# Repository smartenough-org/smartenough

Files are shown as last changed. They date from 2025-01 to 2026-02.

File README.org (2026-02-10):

* SmartEnough
SmartEnough is an open source smart home solution that combines affordable
off-the-shelf hardware with a robust software architecture. Built for people
that don't want to pay premium for each IO they add to the system, who want to
trust the system's reliability and who are not afraid of some tinkering.

** SmartEnough design goals
- Extra cheap hardware: doable by hand (soldering iron or breadboard) and
  upgradable to something more sturdy with ordered PCBs. 48+ IO per single board
  possible and way cheaper $/IO than in any available commercial solutions.
- Robust, resiliant, secure: communication and power over twisted pair cables -
  no batteries, no radio, no cloud.
- Supports house wiring in "constellation of star topologies". We don't have a
  device in each light switch or socket, but neither are we limited to a single
  central control point. Cables from lights/shutters and switches should meet
  somewhere in one or more electrical boxes that are connected together with a
  twisted pair cable to form a CAN bus. Bus can span multiple devices in single
  electrical box, or connect multiple points in a bus or semi-bus configuration.
- Instant response to input.
- Event on one board can cause an action on another (eg. stair switches) via a
  bus without requiring a computer and HomeAssistant - eg. stair lighting.
- Can gather door/window/movement sensor data and be used as an alarm system.
- Open & customizable: I'm building it to suit my needs, trying to keep it open
  for any additional sensible functions.
- Integrates with HomeAssistant, but can do a lot without it.

** Resources
The core system software is in two repositories:
- [[https://github.com/smartenough-org/io-ctrl][io-ctrl]]:
  Firmware for IO controller board that handles IO - reads switches and
  sensors, changes outputs. Contains also firmware for hardware part (left side)
  of =CAN<->USB<->MQTT= bridge to talk to HomeAssistant.
- [[https://github.com/smartenough-org/io-gate][io-gate]]:
  computer part of =CAN<->USB<->MQT= bridge (right part) to convert CAN
  messages to MQTT events that can be understood by HomeAssistant.
- Firmware is in Rust, written with Embassy framework for STM32G431 device.
  Should migrate easy enough to other chips assuming enough peripherals are
  available (CAN and USB working together, 128kB+ Flash, 32kB+ RAM).

Rest of the resources include:
- KiCAD (schematic + board) designs for IO controller board (can be used for
  gate as well).
- KiCAD for organized power injection with protection.
- KiCAD for additional ESPHOME boards for less critical components (like
  temperature sensors).
- 3D printing (FreeCad) designs for DIN rail (mount in electrical boxes) and
  other project boxes for boards (OpenSCAD).
- This repository in addition can contain anything smarthome related I might
  publish (eg. some micropython watering experiments)

** Example deployment
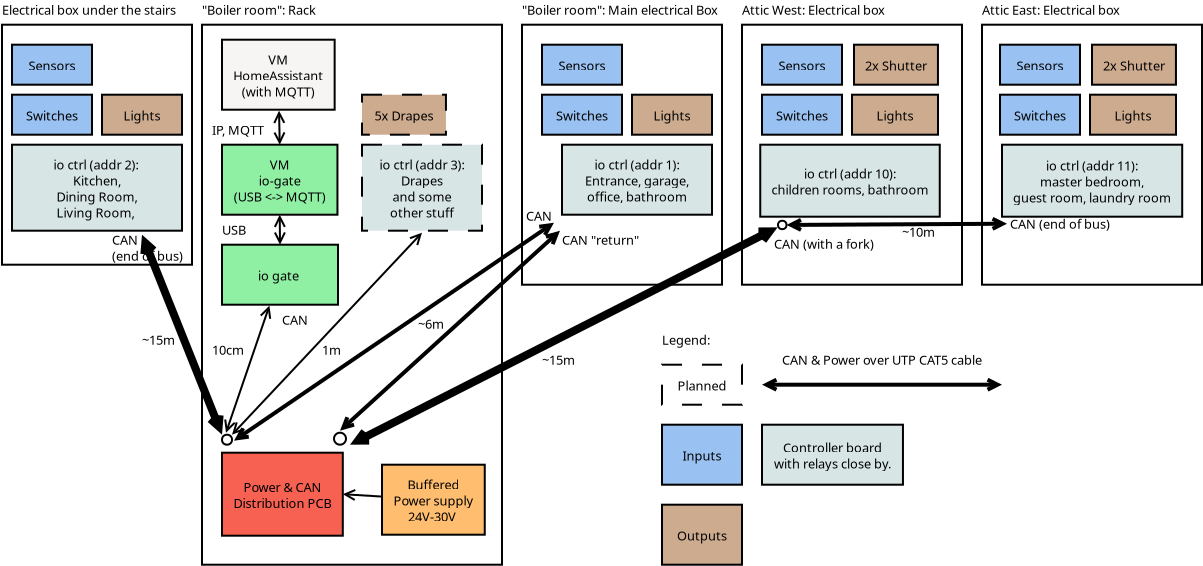
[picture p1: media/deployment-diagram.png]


That's my currently working deployment. NOTE: CAN should not be a star, it
should be a bus. Hence in one case I send CAN signal back over another cable
pair in the same cable to "flatten" it out. Bus gets longer (it's around 50m
total), but stubs are shorter.

*** Connecting cables
I use two pairs for power, one for CAN and one for optional CAN return and a bit
weird RJ45 wiring to indicate the cable is a "SMART" cable not Ethernet. I also
mark those in a visible way. Anything will work as long as CAN and FORWARD is in
the same twisted pair (my mapping will work with normal T568B too).

| T568B | CAN  |   |                       |
|-------+------+---+-----------------------|
| w-o   | w-o  | 1 | CAN_L                 |
| o     | o    | 2 | CAN_H                 |
| w-g   | w-g  | 3 | IN POWER, 24V         |
| bl    | g    | 4 | IN POWER, GND (swap!) |
| w-bl  | w-bl | 5 | IN POWER, 24V         |
| g     | bl   | 6 | IN POWER, GND (swap!) |
| w-br  | w-br | 7 | CAN_L FORWARD         |
| br    | br   | 8 | CAN_H FORWARD         |

*** CAN configuration
I use CAN because it's a multi-master bus, no "leader" device on the BUS needs
to poll for data from "following" devices. When input event occurs or output
changes state a board broadcasts a message on the bus. Another board can see
this message and react by changing it's outputs.

Gate is a special device that serves as a bidirectional =CAN<->USB<->MQTT=
bridge. It receives CAN messages, converts them and publishes them on MQTT. It
also subscribes to MQTT topics and if something is published there it sends a
CAN request to for example toggle an Output.

I use 250kbps CAN speed and 11-bit addressing. I opted for a simple CAN protocol
(as opposed to more versatile CANopen). Address relates to a "message" more than
a "sender/receiver" and is used in determining the priority on the bus. Given
that:
- Messages must be properly unique,
- lower values have higher priorities,
- we want at least 64 devices on the bus,
I picked 6 bit for device address and 5 for message type (32 different message
types). Format: =TTTTTAAAAAA (T)ype + (A)ddress=.

Reporting errors, propagating output/input changes, setting output has higher
priority than requesting status, reporting status, time announcements or some
debug ping/pong messages.

Message body consists of up to 8 bytes of data, system typically uses 2-3.
Example: Request output change has 2 bytes: Index of output to change and byte
representing state (Off, On, Toggle). Message address points at the device that
should change output ("destination").

Message "Output changed" has similarly output index and state (Off, On), but
address points to a message source instead. I don't use RTR (remote frames).

Conscise list of used commands (but see message.rs for details):
- ERROR 0x02 - Error happened.
- OUTPUT_CHANGED 0x04 - My output changed
- INPUT_CHANGED 0x05 -  My input was changed
- SET_OUTPUT 0x08 - Set output X to Y (or invert state)
- CALL_PROC 0x0A - Call a predefined procedure in VM
- CALL_SHUTTER 0x0B - Pass command to Shutter code
- STATUS_IO 0x0E - My current IO status, not necessarily changed.
- INFO 0x12 - Similar to ERROR, but low priority (eg. Device started)
- PONG 0x1D
- PING 0x1E

Call Shutter is longest command as it includes a shutter index and a command
byte that can contain a height and a tilt of the shutter.

** IO Controller MainBoard
For details on components and software see
[[https://github.com/smartenough-org/io-ctrl][io-ctrl]].

This board controls IOs when paired with some relay/SSR module. It sits in an
electrical box where it can read signals from light switches and control power
to lighting. It's talks with the world via classical twisted pair cable: CAT5e
UTP. Cable carries power (24V+) and a CAN bus.

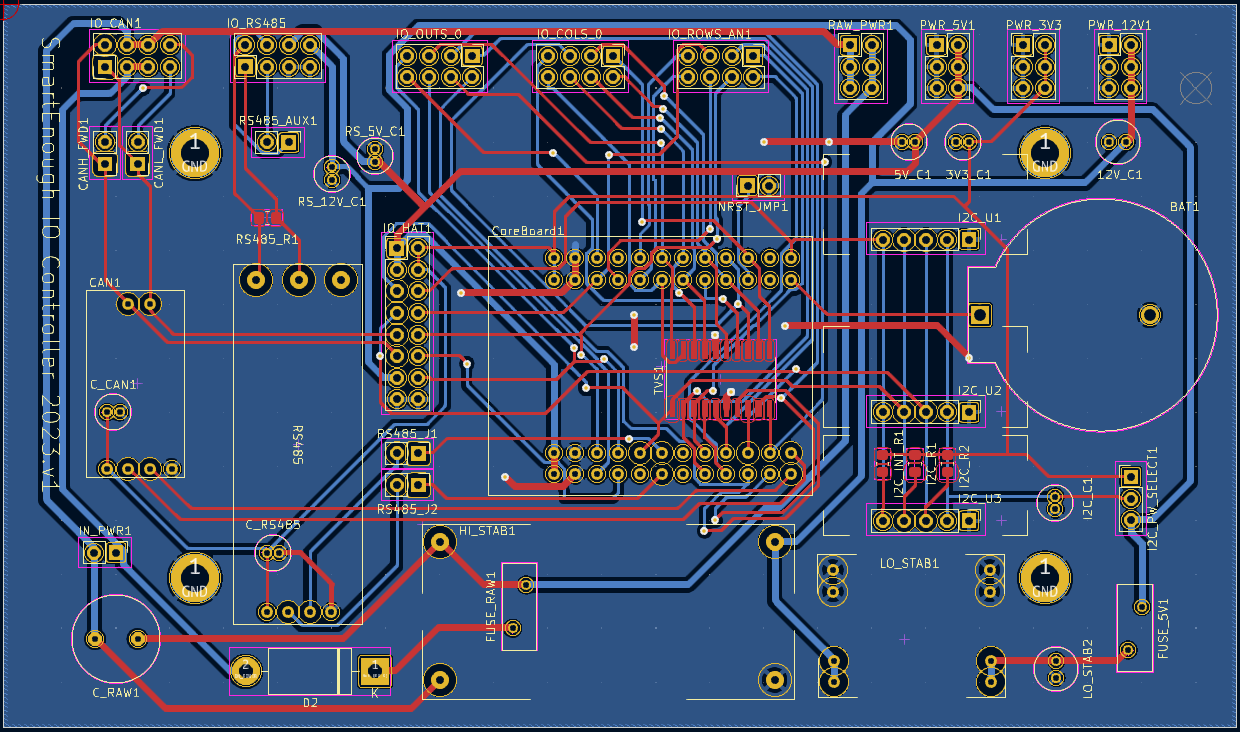
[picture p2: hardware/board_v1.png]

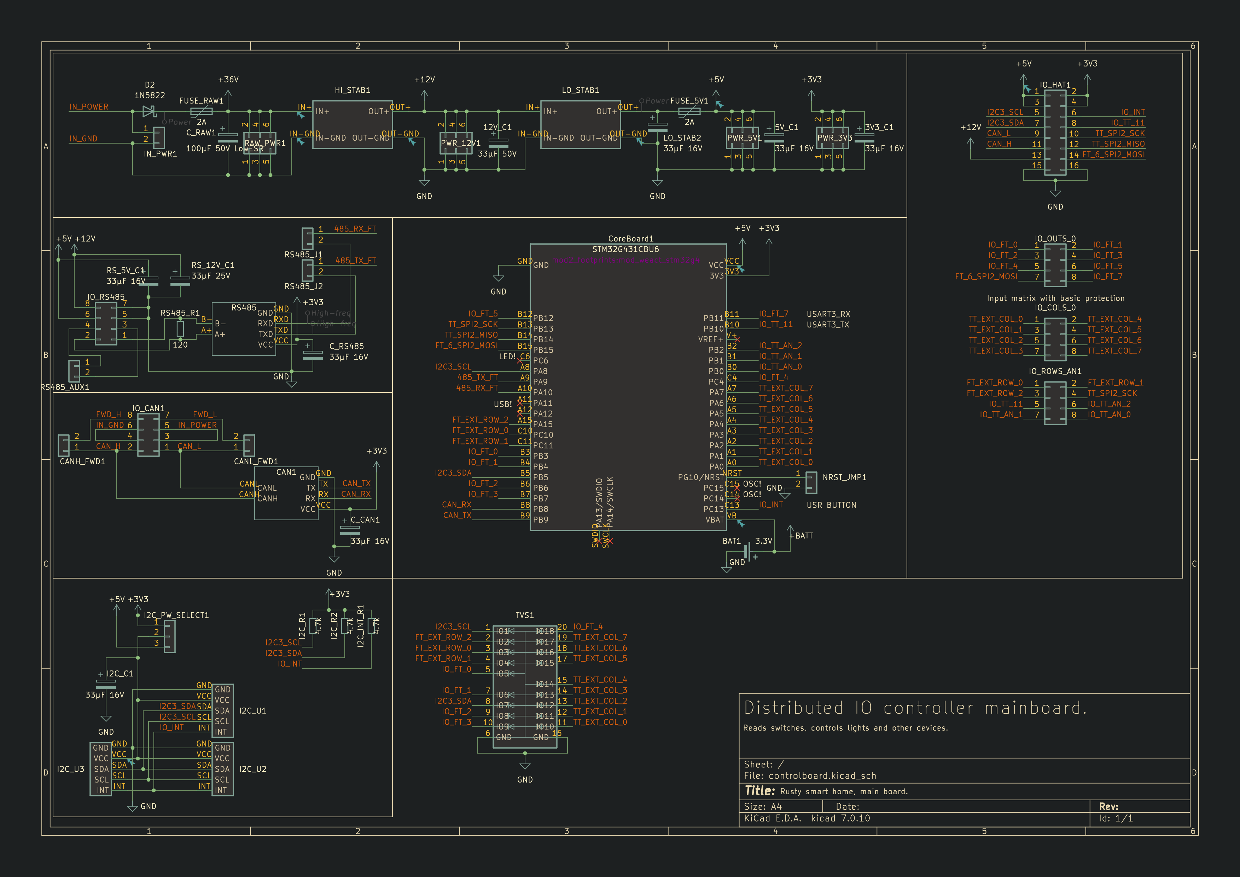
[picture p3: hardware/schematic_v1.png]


** Power distribution board
Power board distributes power with some protection (capacitors, resettable
individual fuses, main fuses, zener diodes to limit voltage, diodes to prevent
invalid polarization). It also connects CAN BUS together in configured various
ways (directly, or using FORWARD pair). In general it allows me to connect the
cables from boards in the main central hub easily.

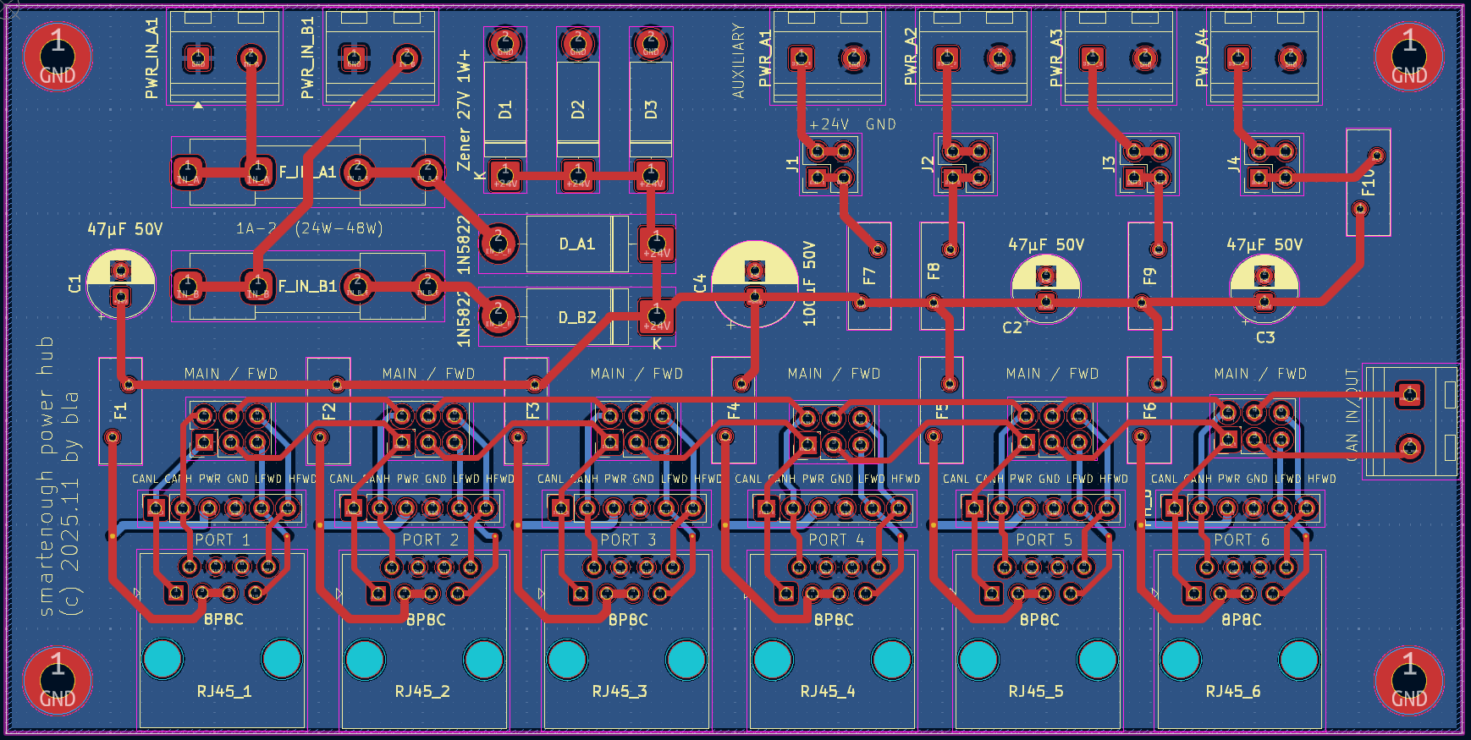
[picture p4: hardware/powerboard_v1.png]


** ESPHome "Uniboard"
It's not strictly part of my main smarthome. A universal PCB board for ESP32 S2
Mini modules I have. It has power stabilization, 1-wire pull-up, some analog
inputs, RS485 interface, four MOSFETs for RGBW or anything else (garage door
control).

I use it with Esphome (over Wifi) where I can't reach with my CAN bus, or where
I don't need the resiliency or just temporarily. For example to gather
temperature readings around heat pump.

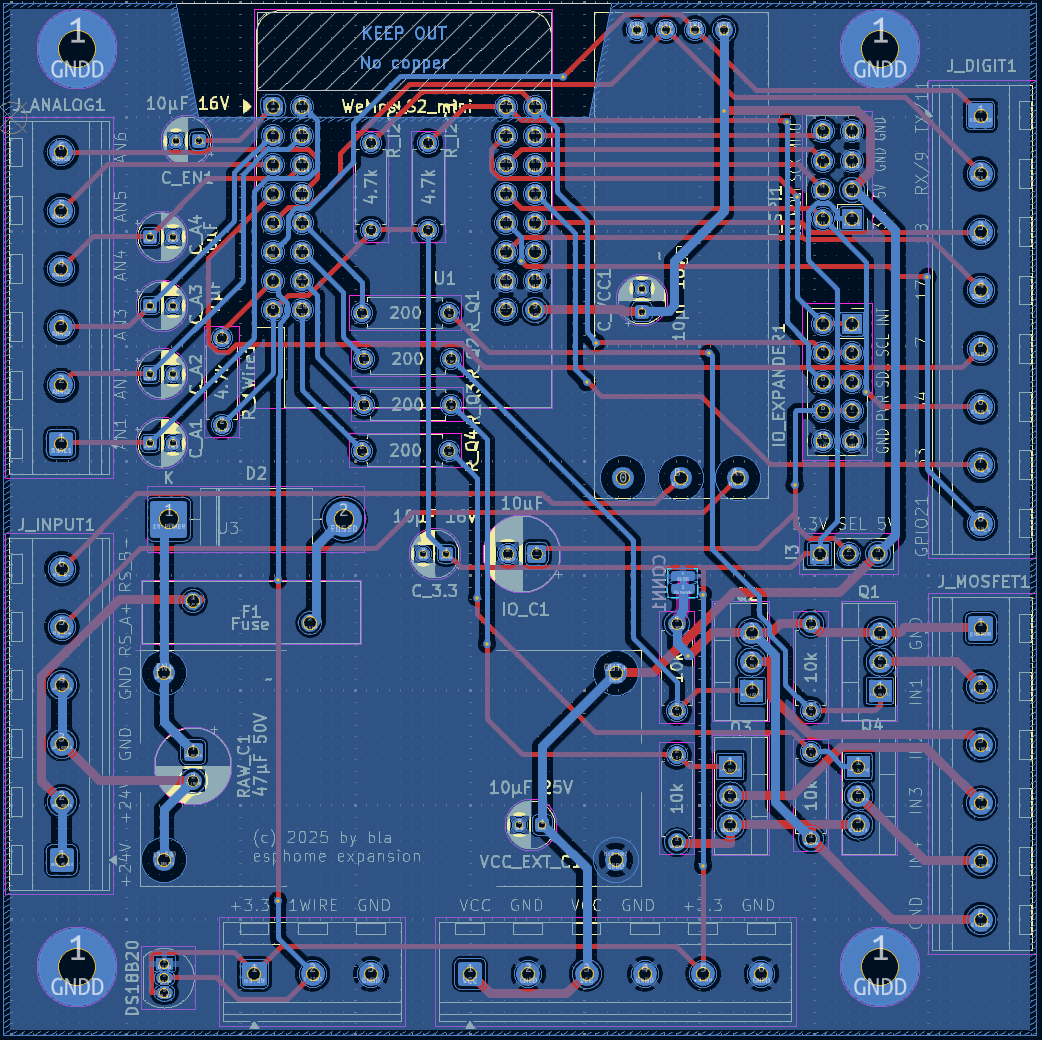
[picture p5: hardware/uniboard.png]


** Greenfinger

Automatic plant watering using ESP8266 (or ESP32) using Micropython.
Integrates with HomeAssistant over MQTT:
- Reports status (humidity, operations).
- Can be controlled over MQTT (more water NOW).

It was 100% stable during a period of about a year. Plants died for unrelated
reasons. ;)

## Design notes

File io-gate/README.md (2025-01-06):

IO-Gate - Computer side
=======================

This is a part of a `CAN <-> Home Assistant` bridge that is required to control
the `io-ctrl` boards from mobile phones, computers, etc.

Example communication schema:

           Distributed and autonomous IO controlling boards:

           +-----------+   +-----------+   +-----------+
           |           |   |           |   |           |
           |  IO Ctrl  |   |  IO Ctrl  |   |  IO Ctrl  |
           |           |   |           |   |           |
           +-----------+   +-----------+   +-----------+
                ||               ||              ||
    CAN Bus:    ||               ||              ||  (termination)
           ++---++---------------++--------------++
           ++---++---------------++--------------++
           ||
           || (termination)     PC, VM, Raspberrypi:
    +-------------+           +-----------------------+
    |             |           |                       |
    |   CAN-USB   |<---USB--->|    IO-Gate Daemon     |
    |   Bridge    |           |                       |
    |             |           |    (Your are here)    |
    +-------------+           +-----------------------+
                                         |
                                         |  LAN / Ethernet
                                         |
       +----------------+         +-------------+
       |                |   LAN   |             |
       | Home Assistant |<------->|    MQTT     |
       |                |         |             |
       +----------------+         +-------------+

- `io-ctrl` boards communicate using a `CAN` bus interface. CAN should be
  terminated using 120 ohm resistors at the ends of a bus.
  They use `io-ctrl` firmware and a `ctrl` binary.
- One board connects the `CAN` to the computer network (`io-ctrl` firmware with
  a `gate` binary).
- `io-gate` daemon communicates with CAN bridge over USB and generates Home
  Assistant compatible messages for the MQTT bus.
- The `io-gate`, Home Assistant and MQTT (usually mosquitto) can share the same
  computer (or a virtual machine).
- High-availability: There can be multiple bridges but only single daemon should
  be running at a time.

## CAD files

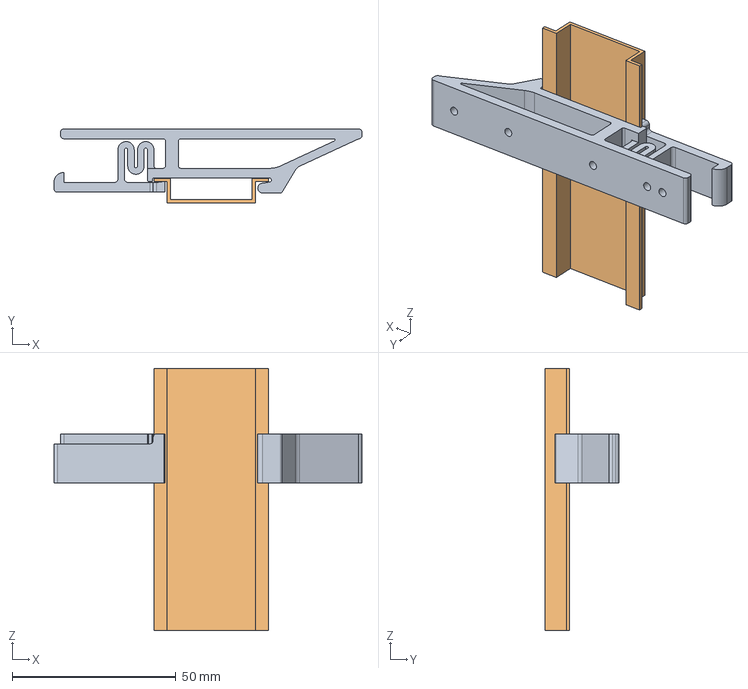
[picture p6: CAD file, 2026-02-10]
fdm_3dcad/universal-din-clip-v3-lower.FCStd
94.0 x 22.6 x 80.0 mm
clip
th-rail

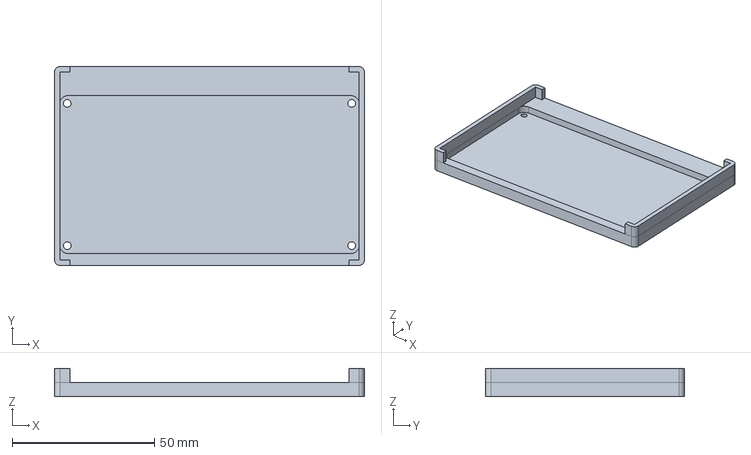
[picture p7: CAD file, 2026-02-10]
fdm_3dcad/SSR_din_case.FCStd
109.0 x 70.0 x 10.0 mm

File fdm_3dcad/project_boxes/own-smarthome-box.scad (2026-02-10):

// Local variables
ventdistance = 14;


include <YAPPgenerator_v3.scad>

pcbLength     = 90;
pcbWidth      = 70;
pcbThickness  =  2;

lidWallHeight  = 20;
baseWallHeight = 15;

paddingFront        = 15;
paddingBack         = 15;
paddingRight        = 15;
paddingLeft         = 15;

standoffPinDiameter = 2.5;
pcbStands = 
[
    [4, 3, 5, -1, 7, yappBoth,
    yappAllCorners]  //-- Add one pcbStand 5mm from the [0,0,0] corners of the PCB
];


cutoutsLid =
[
    //[9,  ((pcbWidth/2)+0.5), 0, 0, 6.5, yappCircle, yappCenter]   // lens
   [20 + ventdistance * 0, 32, 3, 70, 1, yappRoundedRect, yappCenter],
   [20 + ventdistance * 1, 32, 3, 50, 1, yappRoundedRect, yappCenter],
   [20 + ventdistance * 2, 32, 3, 50, 1, yappRoundedRect, yappCenter],
   [20 + ventdistance * 3, 32, 3, 70, 1, yappRoundedRect, yappCenter],
];

cutoutsBase =
[
    //[9,  ((pcbWidth/2)+0.5), 0, 0, 6.5, yappCircle, yappCenter]   // lens
   [20 + ventdistance * 0, 32, 3, 70, 1, yappRoundedRect, yappCenter],
   [20 + ventdistance * 1, 32, 3, 50, 1, yappRoundedRect, yappCenter],
   [20 + ventdistance * 2, 32, 3, 50, 1, yappRoundedRect, yappCenter],
   [20 + ventdistance * 3, 32, 3, 70, 1, yappRoundedRect, yappCenter],
];


echo(ventdistance);
echo(cutoutsLid);

cutoutsFront =
[
    [pcbLength - 40, 10, 40, 15, 0, yappRectangle, yappCenter] // USB
];

cutoutsLeft =
[
    [15, 10, 10, 15, 0, yappRectangle, yappCenter] // USB
];

boxMounts   = 
[
    [15/2, 5, 10, 4, yappRight, yappBase],
    [shellLength - 15 - 5, 5, 10, 4, yappRight, yappBase],
    
    [15/2, 5, 10, 4, yappLeft, yappBase],
    [shellLength - 15 - 5, 5, 10, 4, yappLeft, yappBase],
    
    [shellLength/2 - 10, 5, 10, 4, yappBack, yappBase],
];

debug = false;
showOrientation           = true;       //-> Show the Front/Back/Left/Right labels : only in preview
showPCB                   = true;      //-> Show the PCB in red : only in preview 
showSwitches              = true;      //-> Show the switches (for pushbuttons) : only in preview 
showButtonsDepressed      = false;      //-> Should the buttons in the Lid On view be in the pressed position
showOriginCoordBox        = false;      //-> Shows red bars representing the origin for yappCoordBox : only in preview 
showOriginCoordBoxInside  = false;      //-> Shows blue bars representing the origin for yappCoordBoxInside : only in preview 
showOriginCoordPCB        = false;      //-> Shows blue bars representing the origin for yappCoordBoxInside : only in preview 
showMarkersPCB            = false;      //-> Shows black bars corners of the PCB : only in preview 
showMarkersCenter         = false;      //-> Shows magenta bars along the centers of all faces  


snapJoins   =   
[
   [12, 5, yappLeft, yappRight],
   [(pcbLength+paddingFront*2)/2, 5, yappLeft, yappRight],
   [(pcbLength+paddingFront*2)-12, 5, yappLeft, yappRight]
];

YAPPgenerate();

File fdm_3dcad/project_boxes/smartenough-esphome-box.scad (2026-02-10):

// esphome uni board.

/*
      padding-back|<------pcb length --->|<padding-front
                            RIGHT
        0    X-axis ---> 
        +----------------------------------------+   ---
        |                                        |    ^
        |                                        |   padding-right 
      Y |                                        |    v
      | |    -5,y +----------------------+       |   ---              
 B    a |         | 0,y              x,y |       |     ^              F
 A    x |         |                      |       |     |              R
 C    i |         |                      |       |     | pcb width    O
 K    s |         |                      |       |     |              N
        |         | 0,0              x,0 |       |     v              T
      ^ |    -5,0 +----------------------+       |   ---
      | |                                        |    padding-left
      0 +----------------------------------------+   ---
        0    X-as --->
                          LEFT
*/





// Local variables
ventdistance = 14;


include <YAPPgenerator_v3.scad>

printBaseShell      = true;
printLidShell       = true;

wallThickness = 3.2;
ridgeSlack = 0.4;

printerLayerHeight = 0.2;

pcbLength     = 90;
pcbWidth      = 90;
pcbThickness  =  2;

lidWallHeight  = 15;
baseWallHeight = 20;

paddingFront        = 5;
paddingBack         = 5;
paddingRight        = 15;
paddingLeft         = 15;

standoffHeight = 10;
standoffDiameter = 8;
standoffPinDiameter = 3.6;  
standoffHoleSlack = 0.0;


pcb =
[
  ["Main",              pcbLength, pcbWidth,    0,0,    pcbThickness,  standoffHeight, standoffDiameter, standoffPinDiameter, standoffHoleSlack]
 //,["4x SSR",  57, 55,  0, pcbWidth + 10,  1.6,  3, 7, 2.4]
 //,["Voltage Detect 2",  15.1,71.5+3,  pcbLength + 4 + 15.1, 0,  1.6,  3, 7, 2.4]
];


pcbStands = 
[
    //[4, 3, 5, -1, 7, yappBoth, yappAllCorners]  //-- Add one pcbStand 5mm from the [0,0,0] corners of the PCB
    
    // Two left
    [4, 6.4, yappBaseOnly, yappHole],  //-- Add one pcbStand 5mm from the [0,0,0] corners of the PCB
    [pcbLength - 6, 6.4, yappBaseOnly, yappHole],
    
    // Two right
    [4, pcbWidth - 13.6, yappBaseOnly, yappHole],
    [pcbLength - 6, pcbWidth - 13.6, yappBaseOnly, yappHole],
];

connectors = [
    [-1.73, -11.73, 
     0, // Height related to PCB
     3.1, // Screw 
     7, // Screw head. Computer screw has <7mm
     3.6, // Insert diameter 
     8.5, // Outside diameter
     yappAllCorners, yappThroughLid],
    //[pcbLength, -10, 0, 3, 4, 3, 5],
];

cutoutsLid =
[
   // [9,  ((pcbWidth/2)+0.5), 0, 0, 6.5, yappCircle, yappCenter]   // lens
   // from back, from left, width, length, radius
   /*
   [20 + ventdistance * 0, pcbWidth/2 - 70/2, 3, 70, 1, yappRoundedRect],
   [20 + ventdistance * 1, pcbWidth/2 - 50/2, 3, 50, 1, yappRoundedRect],
   [20 + ventdistance * 2, pcbWidth/2 - 50/2, 3, 50, 1, yappRoundedRect],
   [20 + ventdistance * 3, pcbWidth/2 - 70/2, 3, 70, 1, yappRoundedRect],
   */
];

cutoutsBase =
[
    //[9,  ((pcbWidth/2)+0.5), 0, 0, 6.5, yappCircle, yappCenter]   // lens
  // [20 + ventdistance * 0, 32, 3, 70, 1, yappRoundedRect, yappCenter],
  // [20 + ventdistance * 1, 32, 3, 50, 1, yappRoundedRect, yappCenter],
  // [20 + ventdistance * 2, 32, 3, 50, 1, yappRoundedRect, yappCenter],
  // [20 + ventdistance * 3, 32, 3, 70, 1, yappRoundedRect, yappCenter],
];


echo(ventdistance);
echo(cutoutsLid);

// pos, pos, width, height, rect|circle, yappCenter

cutoutsFront = [
   [12, -3, 7+16+35, 13, 0, yappRectangle], // 1 Wire
   
];

cutoutsLeft = [
   [5, -3, 30, 13, 0, yappRectangle], // ANALOG
   [pcbWidth-13-30, -3, 30, 13, 0, yappRectangle], // INPUT RS/PWR
];

cutoutsRight = [
   [5, -3, 40, 13, 0, yappRectangle], // DIGIT
   [pcbWidth-7-25, -3, 25, 13, 0, yappRectangle], // MOSFET
];

boxMounts = [
    [15/2, 5, 10, 4, yappRight, yappBase],
    [shellLength - 15 - 5, 5, 10, 4, yappRight, yappBase],
    
    [15/2, 5, 10, 4, yappLeft, yappBase],
    [shellLength - 15 - 5, 5, 10, 4, yappLeft, yappBase],
    
    [shellLength/2 - 10, 5, 10, 4, yappBack, yappBase],
];

debug                = false;
showOrientation      = true;      //-> Show the Front/Back/Left/Right labels : only in preview
showPCB              = true;      //-> Show the PCB in red : only in preview 
showSwitches         = true;      //-> Show the switches (for pushbuttons) : only in preview 
showButtonsDepressed = false;     //-> Should the buttons in the Lid On view be in the pressed position
showOriginCoordBox   = false;     //-> Shows red bars representing the origin for yappCoordBox : only in preview 
showOriginCoordBoxInside  = false;  //-> Shows blue bars representing the origin for yappCoordBoxInside : only in preview 
showOriginCoordPCB        = false;  //-> Shows blue bars representing the origin for yappCoordBoxInside : only in preview 
showMarkersPCB            = false;  //-> Shows black bars corners of the PCB : only in preview 
showMarkersCenter         = false;  //-> Shows magenta bars along the centers of all faces  


snapJoins   =   
[
  // [12, 5, yappLeft, yappRight],
  // [(pcbLength+paddingFront*2)/2, 5, yappLeft, yappRight],
  // [(pcbLength+paddingFront*2)-12, 5, yappLeft, yappRight]
];

YAPPgenerate();

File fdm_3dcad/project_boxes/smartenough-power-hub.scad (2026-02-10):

// esphome uni board.

/*
      padding-back|<------pcb length --->|<padding-front
                            RIGHT
        0    X-axis ---> 
        +----------------------------------------+   ---
        |                                        |    ^
        |                                        |   padding-right 
      Y |                                        |    v
      | |    -5,y +----------------------+       |   ---              
 B    a |         | 0,y              x,y |       |     ^              F
 A    x |         |                      |       |     |              R
 C    i |         |                      |       |     | pcb width    O
 K    s |         |                      |       |     |              N
        |         | 0,0              x,0 |       |     v              T
      ^ |    -5,0 +----------------------+       |   ---
      | |                                        |    padding-left
      0 +----------------------------------------+   ---
        0    X-as --->
                          LEFT
*/





// Local variables
ventdistance = 14;

screw_diam = 3.1;
screw_head = 6; // Screw head. Computer screw has <7mm
insert_diam = 3.6; // Insert diameter 
screw_pylon_diam = 8.5; // Outside diameter

include <YAPPgenerator_v3.scad>

printBaseShell      = false;
printLidShell       = true;

wallThickness = 3.2;
ridgeSlack = 0.2; // Was 0.4, but that's too much.

printerLayerHeight = 0.2;

pcbLength     = 70;
pcbWidth      = 140;
pcbThickness  =  1.5;

lidWallHeight  = 17; // lid+base - pcbthickness - standoffheight?
baseWallHeight = 15;

roundRadius = 1.5;

// SSRs have 22mm height from bottom of PCB (as mounted).
// (20+15) - 7 - 1 <- They should fit.

paddingFront        = 10;
paddingBack         = 10;
paddingRight        = 10;
paddingLeft         = 10;

standoffHeight = 7;
standoffDiameter = 8;
standoffPinDiameter = 3.6;  
standoffHoleSlack = 0.0;

//  Parameters:
//   Required:
//    p(0) = name
//    p(1) = length
//    p(2) = width
//    p(3) = posx
//    p(4) = posy
//    p(5) = Thickness
//    p(6) = standoffHeight 
//    p(7) = standoffDiameter
//    p(8) = standoffPinDiameter
//    p(9) = standoffHoleSlack (default to 0.4)
//   Optional:

//The following can be used to get PCB values elsewhere in the script - not in pcb definition. 
//If "PCB Name" is omitted then "Main" is used
//  pcbLength           --> pcbLength("PCB Name")
//  pcbWidth            --> pcbWidth("PCB Name")
//  pcbThickness        --> pcbThickness("PCB Name") 
//  standoffHeight      --> standoffHeight("PCB Name") 
//  standoffDiameter    --> standoffDiameter("PCB Name") 
//  standoffPinDiameter --> standoffPinDiameter("PCB Name") 
//  standoffHoleSlack   --> standoffHoleSlack("PCB Name") 

pcb =
[
  ["Main",              
  pcbLength, pcbWidth,    
  0,0,    
  pcbThickness,  standoffHeight, standoffDiameter, standoffPinDiameter, standoffHoleSlack],
];

//  Parameters:
//   Required:
//    p(0) = posx
//    p(1) = posy
//   Optional:
//    p(2) = Height to bottom of PCB : Default = standoff_Height
//    p(3) = PCB Gap : Default = -1 : Default for yappCoordPCB=pcb_Thickness, yappCoordBox=0
//    p(4) = standoff_Diameter    Default = standoff_Diameter;
//    p(5) = standoff_PinDiameter Default = standoff_PinDiameter;
//    p(6) = standoff_HoleSlack   Default = standoff_HoleSlack;
//    p(7) = filletRadius (0 = auto size)
//    n(a) = { <yappBoth> | yappLidOnly | yappBaseOnly }
//    n(b) = { <yappPin>, yappHole } // Baseplate support treatment
//    n(c) = { yappAllCorners, yappFrontLeft | <yappBackLeft> | yappFrontRight | yappBackRight }
//    n(d) = { <yappCoordPCB> | yappCoordBox | yappCoordBoxInside }
//    n(e) = { yappNoFillet }
//    n(f) = [yappPCBName, "XXX"] : {Specify a PCB defaults to "Main"
//-------------------------------------------------------------------

pcbStands = 
[
    //[4, 3, 5, -1, 7, yappBoth, yappAllCorners]  //-- Add one pcbStand 5mm from the [0,0,0] corners of the PCB
    
    // Two left
    [5.15, 5.15, yappBaseOnly, yappHole],  //-- Add one pcbStand 5mm from the [0,0,0] corners of the PCB
    [pcbLength - 5.15, 5.15, yappBaseOnly, yappHole],
    
    // Two right
    [5.15, pcbWidth - 5.15, yappBaseOnly, yappHole],
    [pcbLength - 5.15, pcbWidth - 5.2, yappBaseOnly, yappHole],
];

//===================================================================
//  *** Connectors ***
//  Standoffs with hole through base and socket in lid for screw type connections.
//-------------------------------------------------------------------
//  Default origin = yappCoordBox: box[0,0,0]
//  
//  Parameters:
//   Required:
//    p(0) = posx
//    p(1) = posy
//    p(2) = pcbStandHeight
//    p(3) = screwDiameter
//    p(4) = screwHeadDiameter (don't forget to add extra for the fillet)
//    p(5) = insertDiameter
//    p(6) = outsideDiameter
//   Optional:
//    p(7) = PCB Gap : Default = -1 : Default for yappCoordPCB=pcbThickness, yappCoordBox=0
//    p(8) = filletRadius : Default = 0/Auto(0 = auto size)
//    n(a) = { <yappAllCorners>, yappFrontLeft | yappFrontRight | yappBackLeft | yappBackRight }
//    n(b) = { <yappCoordBox> | yappCoordPCB |  yappCoordBoxInside }
//    n(c) = { yappNoFillet }
//    n(d) = [yappPCBName, "XXX"] : {XXX = the PCB name: Default "Main"}

connectors = [
    // Left side (Back, front)
    [5.5, 5.5, 
     10, // Height related to PCB
     screw_diam, // Screw 
     screw_head, // Screw head. Computer screw has <7mm
     insert_diam, // Insert diameter 
     screw_pylon_diam, // Outside diameter
     yappAllCorners,
     yappThroughLid, 
     yappCoordBoxInside],
     
    //[pcbLength, -10, 0, 3, 4, 3, 5],
];


//===================================================================
//  *** Cutouts ***
//    There are 6 cutouts one for each surface:
//      cutoutsBase (Bottom), cutoutsLid (Top), cutoutsFront, cutoutsBack, cutoutsLeft, cutoutsRight
//-------------------------------------------------------------------
//  Default origin = yappCoordBox: box[0,0,0]  
//
//                        Required                Not Used        Note
//----------------------+-----------------------+---------------+------------------------------------
//  yappRectangle       | width, length         | radius        |
//  yappCircle          | radius                | width, length |
//  yappRoundedRect     | width, length, radius |               |     
//  yappCircleWithFlats | width, radius         | length        | length=distance between flats
//  yappCircleWithKey   | width, length, radius |               | width = key width length=key depth
//  yappPolygon         | width, length         | radius        | yappPolygonDef object must be
//                      |                       |               | provided
//----------------------+-----------------------+---------------+------------------------------------
//
//  Parameters:     
//   Required:      
//    p(0) = from Back
//    p(1) = from Left
//    p(2) = width
//    p(3) = length
//    p(4) = radius 
//    p(5) = shape : { yappRectangle | yappCircle | yappPolygon | yappRoundedRect 
//                     | yappCircleWithFlats | yappCircleWithKey }
//  Optional:
//    p(6) = depth : Default = 0/Auto : 0 = Auto (plane thickness)
//    p(7) = angle : Default = 0
//    n(a) = { yappPolygonDef } : Required if shape = yappPolygon specified -
//    n(b) = { yappMaskDef } : If a yappMaskDef object is added it will be used as a mask 
//                             for the cutout.
//    n(c) = { [yappMaskDef, hOffset, vOffset, rotation] } : If a list for a mask is added 
//                              it will be used as a mask for the cutout. With the Rotation 
//                              and offsets applied. This can be used to fine tune the mask
//                              placement within the opening.
//    n(d) = { <yappCoordPCB> | yappCoordBox | yappCoordBoxInside }
//    n(e) = { <yappOrigin>, yappCenter }
//    n(f) = { <yappGlobalOrigin>, yappLeftOrigin } // Only affects Top(lid), Back and Right Faces
//    n(g) = [yappPCBName, "XXX"] : {Specify a PCB defaults to "Main"

cutoutsLid =
[
   // [9,  ((pcbWidth/2)+0.5), 0, 0, 6.5, yappCircle, yappCenter]   // lens
   // from back, from left, width, length, radius
   /*
   [20 + ventdistance * 0, pcbWidth/2 - 70/2, 3, 70, 1, yappRoundedRect],
   [20 + ventdistance * 1, pcbWidth/2 - 50/2, 3, 50, 1, yappRoundedRect],
   [20 + ventdistance * 2, pcbWidth/2 - 50/2, 3, 50, 1, yappRoundedRect],
   [20 + ventdistance * 3, pcbWidth/2 - 70/2, 3, 70, 1, yappRoundedRect],
   */
   [30, 20,
    shellHeight+20, shellWidth - 20*2 , 
    5,
    yappRoundedRect, undef, undef, maskHoneycomb, yappCoordBox]
];
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

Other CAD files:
fdm_3dcad/project_boxes/YAPPgenerator_v3.scad

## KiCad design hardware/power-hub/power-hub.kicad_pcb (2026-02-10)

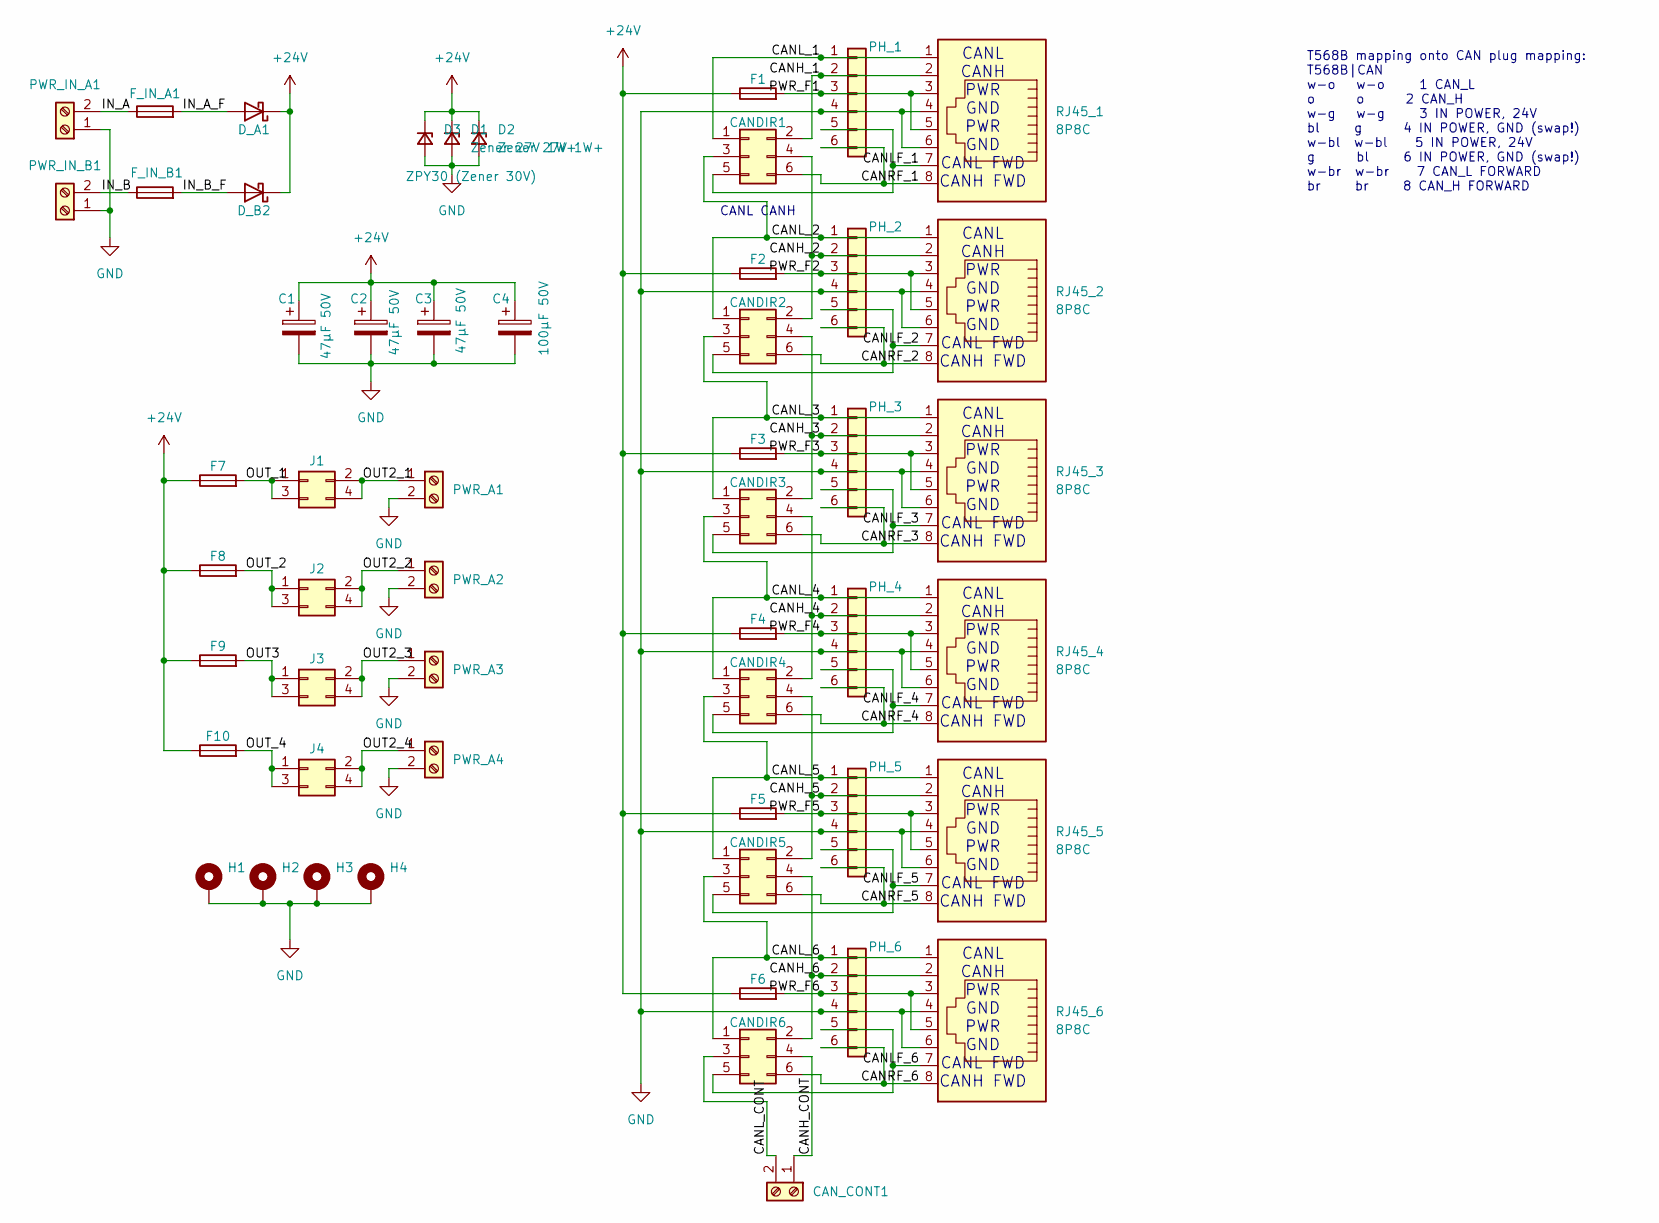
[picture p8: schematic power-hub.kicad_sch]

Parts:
C1, C2, C3: 47µF 50V; CP_Radial_D6.3mm_P2.50mm
C4: 100µF 50V; CP_Radial_D8.0mm_P2.50mm
CANDIR1, CANDIR2, CANDIR3, CANDIR4, CANDIR5, CANDIR6: Conn_02x03_Odd_Even; PinHeader_2x03_P2.54mm_Vertical
CAN_CONT1: Screw_Terminal_01x02; TerminalBlock_RND_205-00232_1x02_P5.08mm_Horizontal
D1, D2: Zener 27V 1W+; D_5W_P12.70mm_Horizontal
D3: ZPY30 (Zener 30V); D_5W_P12.70mm_Horizontal
D_A1: 1N5822; D_DO-201AD_P15.24mm_Horizontal
D_B2: 1N5822; D_DO-201AD_P15.24mm_Horizontal
F1, F2, F3, F4, F5, F6, F7, F8, F9, F10: Fuse; Fuse_BelFuse_0ZRE0016FF_L9.9mm_W3.8mm
F_IN_A1: Fuse; Fuseholder_Clip-5x20mm_Keystone_3517_Inline_P23.11x6.76mm_D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
F_IN_B1: Fuse; Fuseholder_Clip-5x20mm_Keystone_3517_Inline_P23.11x6.76mm_D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
H1, H2, H3, H4: MountingHole_Pad; MountingHole_3.2mm_M3_Pad
J1, J2, J3, J4: Conn_02x02_Odd_Even; PinHeader_2x02_P2.54mm_Vertical
PH_1, PH_2, PH_3, PH_4, PH_5, PH_6: Conn_01x06; PinSocket_1x06_P2.54mm_Vertical
PWR_A1, PWR_A2, PWR_A3, PWR_A4: Screw_Terminal_01x02; TerminalBlock_RND_205-00232_1x02_P5.08mm_Horizontal
PWR_IN_A1: Screw_Terminal_01x02; TerminalBlock_RND_205-00232_1x02_P5.08mm_Horizontal
PWR_IN_B1: Screw_Terminal_01x02; TerminalBlock_RND_205-00232_1x02_P5.08mm_Horizontal
RJ45_1, RJ45_2, RJ45_3, RJ45_4, RJ45_5, RJ45_6: 8P8C; RJ45_OST_PJ012-8P8CX_Vertical

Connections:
+24V: C1.1, C2.1, C3.1, C4.1, D1.1 (K), D2.1 (K), D3.1 (K), D_A1.1 (K), D_B2.1 (K), F1.1, F2.1, F3.1, F4.1, F5.1, F6.1, F7.1, F8.1, F9.1, F10.1
/CANH_1: CANDIR1.2, PH_1.2, RJ45_1.2
/CANH_2: CANDIR1.4, CANDIR2.2, PH_2.2, RJ45_2.2
/CANH_3: CANDIR2.4, CANDIR3.2, PH_3.2, RJ45_3.2
/CANH_4: CANDIR3.4, CANDIR4.2, PH_4.2, RJ45_4.2
/CANH_5: CANDIR4.4, CANDIR5.2, PH_5.2, RJ45_5.2
/CANH_6: CANDIR5.4, CANDIR6.2, PH_6.2, RJ45_6.2
/CANH_CONT: CANDIR6.4, CAN_CONT1.1
/CANLF_1: CANDIR1.5, PH_1.5, RJ45_1.7
/CANLF_2: CANDIR2.5, PH_2.5, RJ45_2.7
/CANLF_3: CANDIR3.5, PH_3.5, RJ45_3.7
/CANLF_4: CANDIR4.5, PH_4.5, RJ45_4.7
/CANLF_5: CANDIR5.5, PH_5.5, RJ45_5.7
/CANLF_6: CANDIR6.5, PH_6.5, RJ45_6.7
/CANL_1: CANDIR1.1, PH_1.1, RJ45_1.1
/CANL_2: CANDIR1.3, CANDIR2.1, PH_2.1, RJ45_2.1
/CANL_3: CANDIR2.3, CANDIR3.1, PH_3.1, RJ45_3.1
/CANL_4: CANDIR3.3, CANDIR4.1, PH_4.1, RJ45_4.1
/CANL_5: CANDIR4.3, CANDIR5.1, PH_5.1, RJ45_5.1
/CANL_6: CANDIR5.3, CANDIR6.1, PH_6.1, RJ45_6.1
/CANL_CONT: CANDIR6.3, CAN_CONT1.2
/CANRF_1: CANDIR1.6, PH_1.6, RJ45_1.8
/CANRF_2: CANDIR2.6, PH_2.6, RJ45_2.8
/CANRF_3: CANDIR3.6, PH_3.6, RJ45_3.8
/CANRF_4: CANDIR4.6, PH_4.6, RJ45_4.8
/CANRF_5: CANDIR5.6, PH_5.6, RJ45_5.8
/CANRF_6: CANDIR6.6, PH_6.6, RJ45_6.8
/IN_A: F_IN_A1.1, PWR_IN_A1.2
/IN_A_F: D_A1.2 (A), F_IN_A1.2
/IN_B: F_IN_B1.1, PWR_IN_B1.2
/IN_B_F: D_B2.2 (A), F_IN_B1.2
/OUT2_1: J1.2, J1.4, PWR_A1.1
/OUT2_2: J2.2, J2.4, PWR_A2.1
/OUT2_3: J3.2, J3.4, PWR_A3.1
/OUT2_4: J4.2, J4.4, PWR_A4.1
/OUT3: F9.2, J3.1, J3.3
/OUT_1: F7.2, J1.1, J1.3
/OUT_2: F8.2, J2.1, J2.3
/OUT_4: F10.2, J4.1, J4.3
/PWR_F1: F1.2, PH_1.3, RJ45_1.3, RJ45_1.5
/PWR_F2: F2.2, PH_2.3, RJ45_2.3, RJ45_2.5
/PWR_F3: F3.2, PH_3.3, RJ45_3.3, RJ45_3.5
/PWR_F4: F4.2, PH_4.3, RJ45_4.3, RJ45_4.5
/PWR_F5: F5.2, PH_5.3, RJ45_5.3, RJ45_5.5
/PWR_F6: F6.2, PH_6.3, RJ45_6.3, RJ45_6.5
GND: C1.2, C2.2, C3.2, C4.2, D1.2 (A), D2.2 (A), D3.2 (A), H1.1, H2.1, H3.1, H4.1, PH_1.4, PH_2.4, PH_3.4, PH_4.4, PH_5.4, PH_6.4, PWR_A1.2, PWR_A2.2, PWR_A3.2, PWR_A4.2, PWR_IN_A1.1, PWR_IN_B1.1, RJ45_1.4, RJ45_1.6, RJ45_2.4, RJ45_2.6, RJ45_3.4, RJ45_3.6, RJ45_4.4, RJ45_4.6, RJ45_5.4, RJ45_5.6, RJ45_6.4, RJ45_6.6

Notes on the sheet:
CANL CANH PWR GND PWR GND CANL FWD CANH FWD
T568B mapping onto CAN plug mapping: T568B|CAN w-o w-o 1 CAN_L o o 2 CAN_H w-g w-g 3 IN POWER, 24V bl g 4 IN POWER, GND (swap!) w-bl w-bl 5 IN POWER, 24V g bl 6 IN POWER, GND (swap!) w-br w-br 7 CAN_L FORWARD br br 8 CAN_H FORWARD
CANL CANH

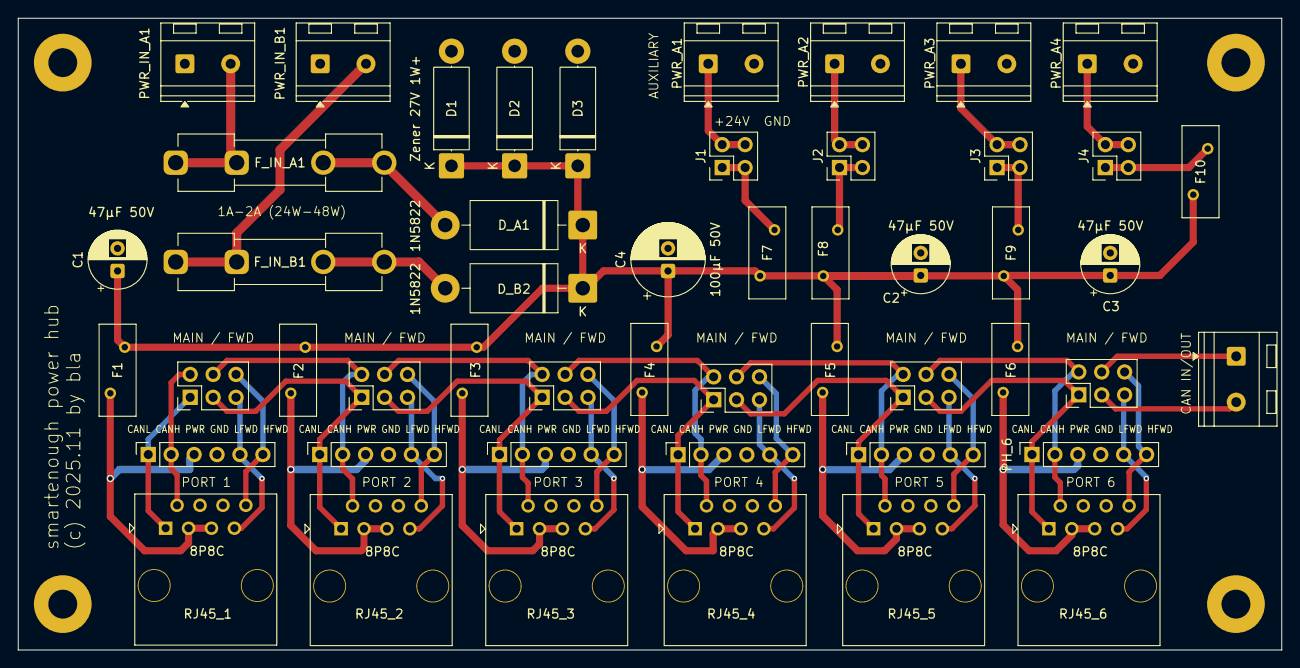
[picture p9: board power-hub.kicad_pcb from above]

Board: 2 copper layers, 140.0 x 70.0 mm, 54 parts (0 on the bottom side), 46 nets.

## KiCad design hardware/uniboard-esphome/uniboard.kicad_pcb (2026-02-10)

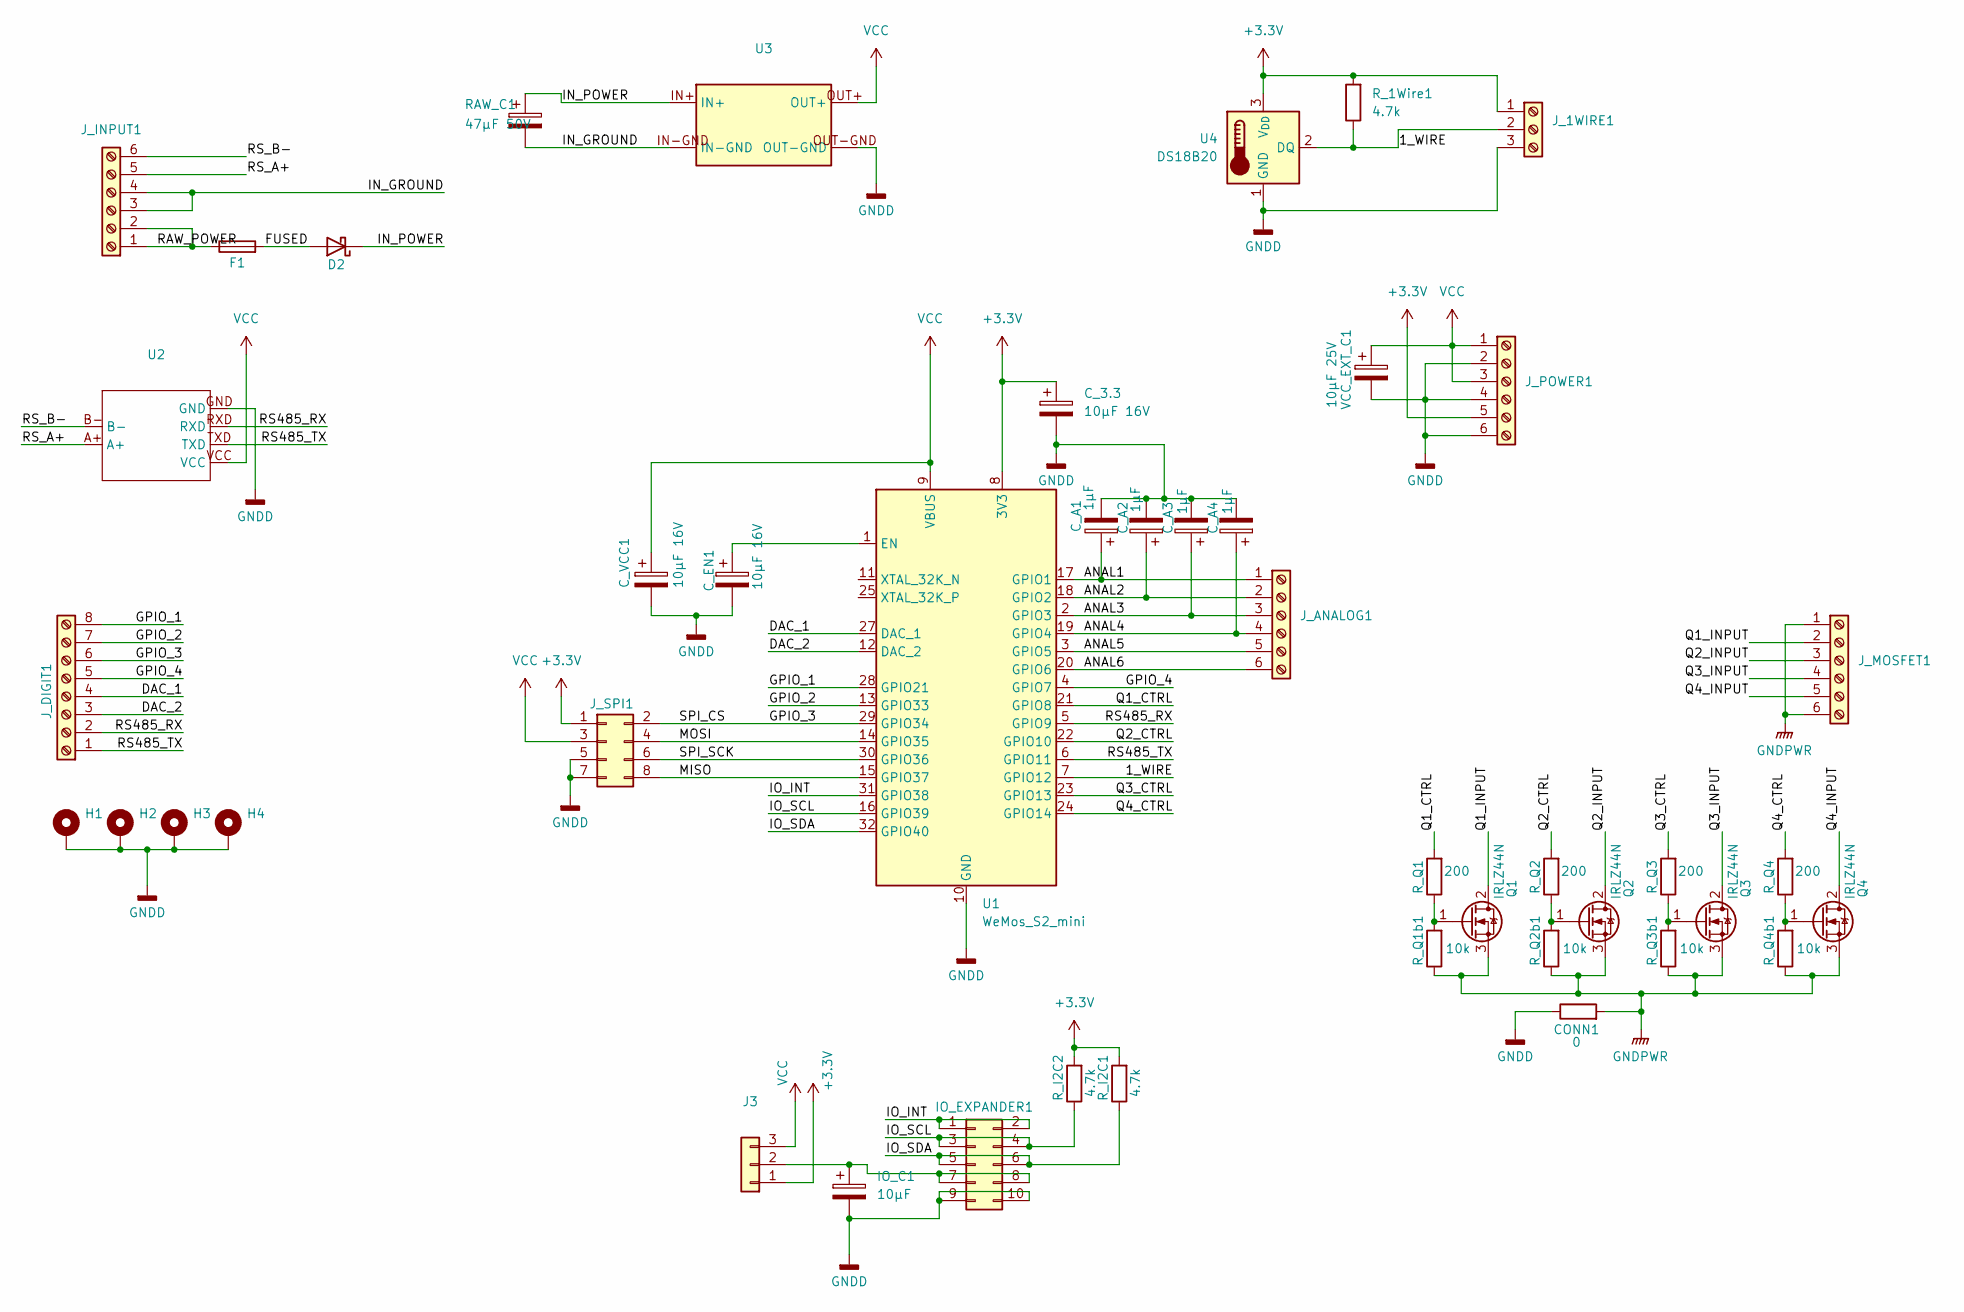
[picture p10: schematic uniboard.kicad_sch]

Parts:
CONN1: 0; R_0508_1220Metric
C_3.3: 10µF 16V; CP_Radial_D4.0mm_P2.00mm
C_A1, C_A2, C_A3, C_A4: 1µF; CP_Radial_D4.0mm_P2.00mm
C_EN1: 10µF 16V; CP_Radial_D4.0mm_P2.00mm
C_VCC1: 10µF 16V; CP_Radial_D4.0mm_P2.00mm
D2: 1N5822; D_DO-201AD_P15.24mm_Horizontal
F1: Fuse; Fuse_BelFuse_0ZRE0100FF_L18.7mm_W5.1mm
H1, H2, H3, H4: MountingHole_Pad; MountingHole_3.2mm_M3_Pad
IO_C1: 10µF; CP_Radial_D6.3mm_P2.50mm
IO_EXPANDER1: Conn_02x05_Odd_Even; PinSocket_2x05_P2.54mm_Vertical
J3: Conn_01x03; PinHeader_1x03_P2.54mm_Vertical
J_1WIRE1: Screw_Terminal_01x03; TerminalBlock_RND_205-00233_1x03_P5.08mm_Horizontal
J_ANALOG1: Screw_Terminal_01x06; TerminalBlock_RND_205-00236_1x06_P5.08mm_Horizontal
J_DIGIT1: Screw_Terminal_01x08; TerminalBlock_RND_205-00238_1x08_P5.08mm_Horizontal
J_INPUT1: Screw_Terminal_01x06; TerminalBlock_RND_205-00236_1x06_P5.08mm_Horizontal
J_MOSFET1: Screw_Terminal_01x06; TerminalBlock_RND_205-00236_1x06_P5.08mm_Horizontal
J_POWER1: Screw_Terminal_01x06; TerminalBlock_RND_205-00236_1x06_P5.08mm_Horizontal
J_SPI1: Conn_02x04_Odd_Even; PinHeader_2x04_P2.54mm_Vertical
Q1, Q2, Q3, Q4: IRLZ44N; TO-220-3_Vertical
RAW_C1: 47µF 50V; CP_Radial_D6.3mm_P2.50mm
R_1Wire1: 4.7k; R_Axial_DIN0207_L6.3mm_D2.5mm_P7.62mm_Horizontal
R_I2C1, R_I2C2: 4.7k; R_Axial_DIN0207_L6.3mm_D2.5mm_P7.62mm_Horizontal
R_Q1, R_Q2, R_Q3, R_Q4: 200; R_Axial_DIN0207_L6.3mm_D2.5mm_P7.62mm_Horizontal
R_Q1b1, R_Q2b1, R_Q3b1, R_Q4b1: 10k; R_Axial_DIN0207_L6.3mm_D2.5mm_P7.62mm_Horizontal
U1: WeMos_S2_mini; WEMOS_S2_mini
U2: mod_hw-0519-rs-485
U3: mod_LM2596
U4: DS18B20; TO-92_Inline
VCC_EXT_C1: 10µF 25V; CP_Radial_D4.0mm_P2.00mm

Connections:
+3.3V: C_3.3.1, J3.1, J_1WIRE1.1, J_POWER1.5, J_SPI1.1, R_1Wire1.2, R_I2C1.2, R_I2C2.2, U1.8 (3V3), U4.3 (V_{DD})
/1_WIRE: J_1WIRE1.2, R_1Wire1.1, U1.7 (GPIO12), U4.2 (DQ)
/ANAL1: C_A1.1, J_ANALOG1.1, U1.17 (GPIO1)
/ANAL2: C_A2.1, J_ANALOG1.2, U1.18 (GPIO2)
/ANAL3: C_A3.1, J_ANALOG1.3, U1.2 (GPIO3)
/ANAL4: C_A4.1, J_ANALOG1.4, U1.19 (GPIO4)
/ANAL5: J_ANALOG1.5, U1.3 (GPIO5)
/ANAL6: J_ANALOG1.6, U1.20 (GPIO6)
/DAC_1: J_DIGIT1.4, U1.27 (DAC_1)
/DAC_2: J_DIGIT1.3, U1.12 (DAC_2)
/FUSED: D2.2 (A), F1.2
/GPIO_1: J_DIGIT1.8, U1.28 (GPIO21)
/GPIO_2: J_DIGIT1.7, U1.13 (GPIO33)
/GPIO_3: J_DIGIT1.6, J_SPI1.2, U1.29 (GPIO34)
/GPIO_4: J_DIGIT1.5, U1.4 (GPIO7)
/IN_GROUND: J_INPUT1.3, J_INPUT1.4, RAW_C1.2, U3.IN-GND
/IN_POWER: D2.1 (K), RAW_C1.1, U3.IN+
/IO_INT: IO_EXPANDER1.1, IO_EXPANDER1.2, U1.31 (GPIO38)
/IO_SCL: IO_EXPANDER1.3, IO_EXPANDER1.4, R_I2C2.1, U1.16 (GPIO39)
/IO_SDA: IO_EXPANDER1.5, IO_EXPANDER1.6, R_I2C1.1, U1.32 (GPIO40)
/MISO: J_SPI1.8, U1.15 (GPIO37)
/MOSI: J_SPI1.4, U1.14 (GPIO35)
/Q1_CTRL: R_Q1.2, U1.21 (GPIO8)
/Q1_INPUT: J_MOSFET1.2, Q1.2 (D)
/Q2_CTRL: R_Q2.2, U1.22 (GPIO10)
/Q2_INPUT: J_MOSFET1.3, Q2.2 (D)
/Q3_CTRL: R_Q3.2, U1.23 (GPIO13)
/Q3_INPUT: J_MOSFET1.4, Q3.2 (D)
/Q4_CTRL: R_Q4.2, U1.24 (GPIO14)
/Q4_INPUT: J_MOSFET1.5, Q4.2 (D)
/RAW_POWER: F1.1, J_INPUT1.1, J_INPUT1.2
/RS485_RX: J_DIGIT1.2, U1.5 (GPIO9), U2.RXD
/RS485_TX: J_DIGIT1.1, U1.6 (GPIO11), U2.TXD
/RS_A+: J_INPUT1.5, U2.A+
/RS_B-: J_INPUT1.6, U2.B-
/SPI_SCK: J_SPI1.6, U1.30 (GPIO36)
GNDD: CONN1.1, C_3.3.2, C_A1.2, C_A2.2, C_A3.2, C_A4.2, C_EN1.2, C_VCC1.2, H1.1, H2.1, H3.1, H4.1, IO_C1.2, IO_EXPANDER1.9, IO_EXPANDER1.10, J_1WIRE1.3, J_POWER1.2, J_POWER1.4, J_POWER1.6, J_SPI1.5, J_SPI1.7, U1.10 (GND), U1.26 (GND), U2.GND, U3.OUT-GND, U4.1 (GND), VCC_EXT_C1.2
GNDPWR: CONN1.2, J_MOSFET1.1, J_MOSFET1.6, Q1.3 (S), Q2.3 (S), Q3.3 (S), Q4.3 (S), R_Q1b1.1, R_Q2b1.1, R_Q3b1.1, R_Q4b1.1
unnamed: IO_C1.1, IO_EXPANDER1.7, IO_EXPANDER1.8, J3.2
unnamed: Q1.1 (G), R_Q1.1, R_Q1b1.2
unnamed: Q2.1 (G), R_Q2.1, R_Q2b1.2
unnamed: Q3.1 (G), R_Q3.1, R_Q3b1.2
unnamed: Q4.1 (G), R_Q4.1, R_Q4b1.2
unnamed: C_EN1.1, U1.1 (EN)
VCC: C_VCC1.1, J3.3, J_POWER1.1, J_POWER1.3, J_SPI1.3, U1.9 (VBUS), U2.VCC, U3.OUT+, VCC_EXT_C1.1

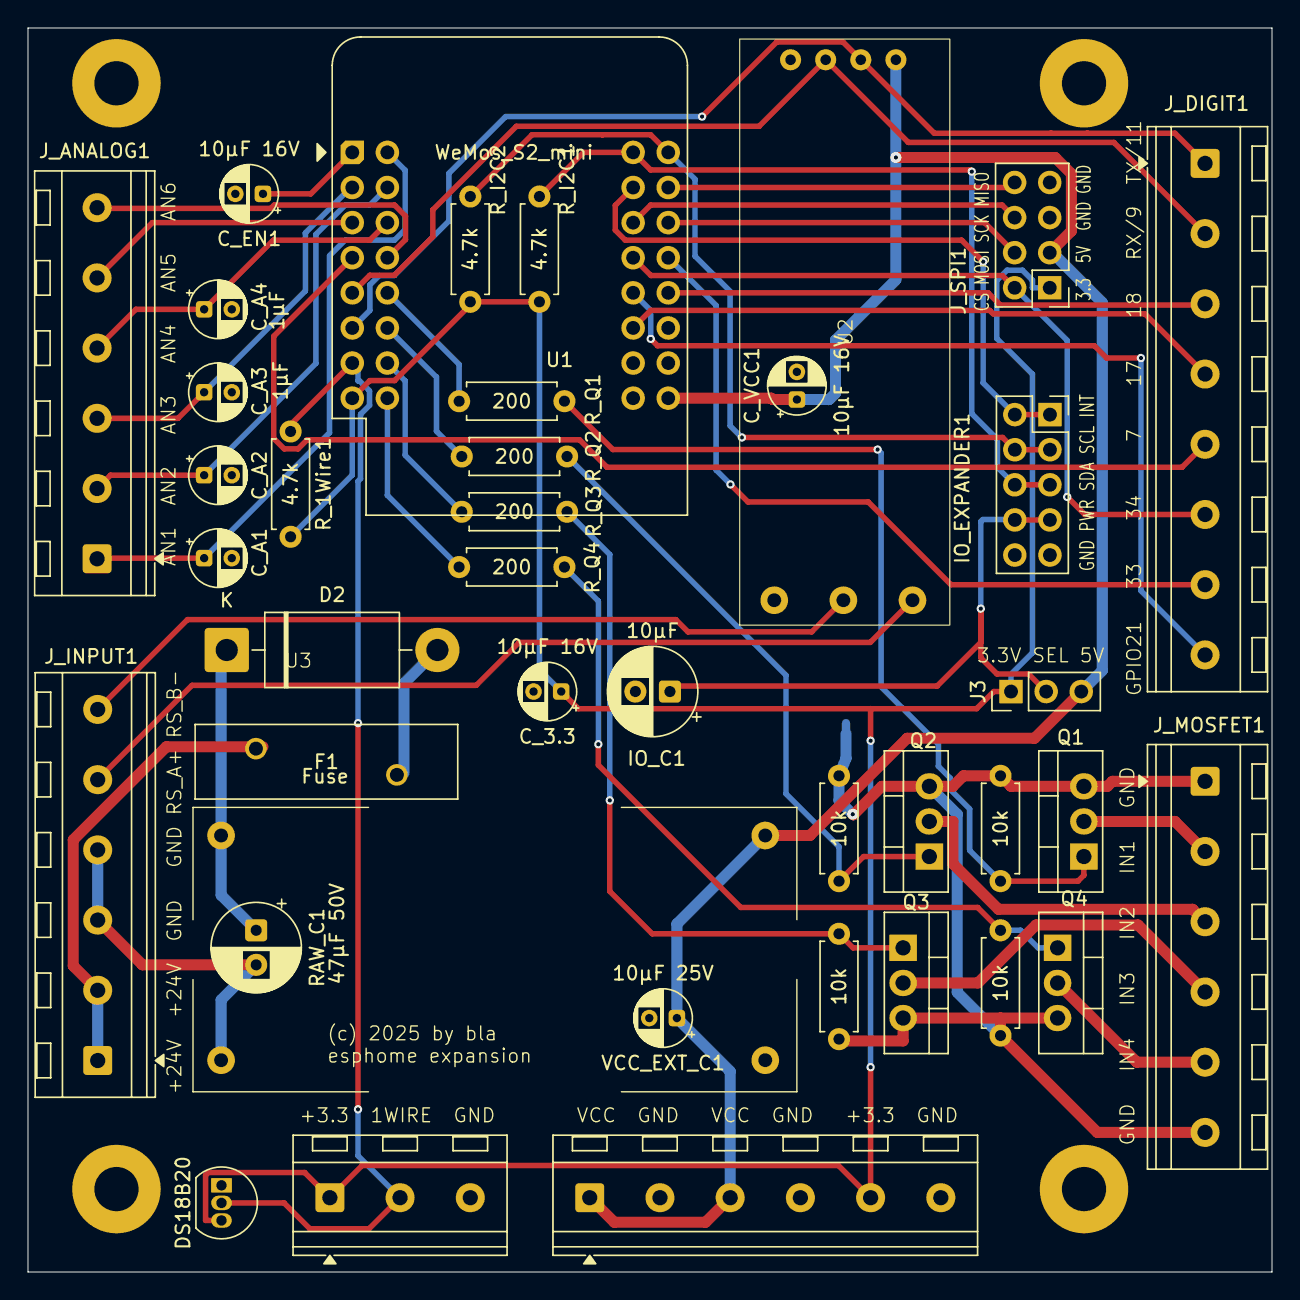
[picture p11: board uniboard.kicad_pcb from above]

Board: 2 copper layers, 90.0 x 90.0 mm, 45 parts (1 on the bottom side), 45 nets.

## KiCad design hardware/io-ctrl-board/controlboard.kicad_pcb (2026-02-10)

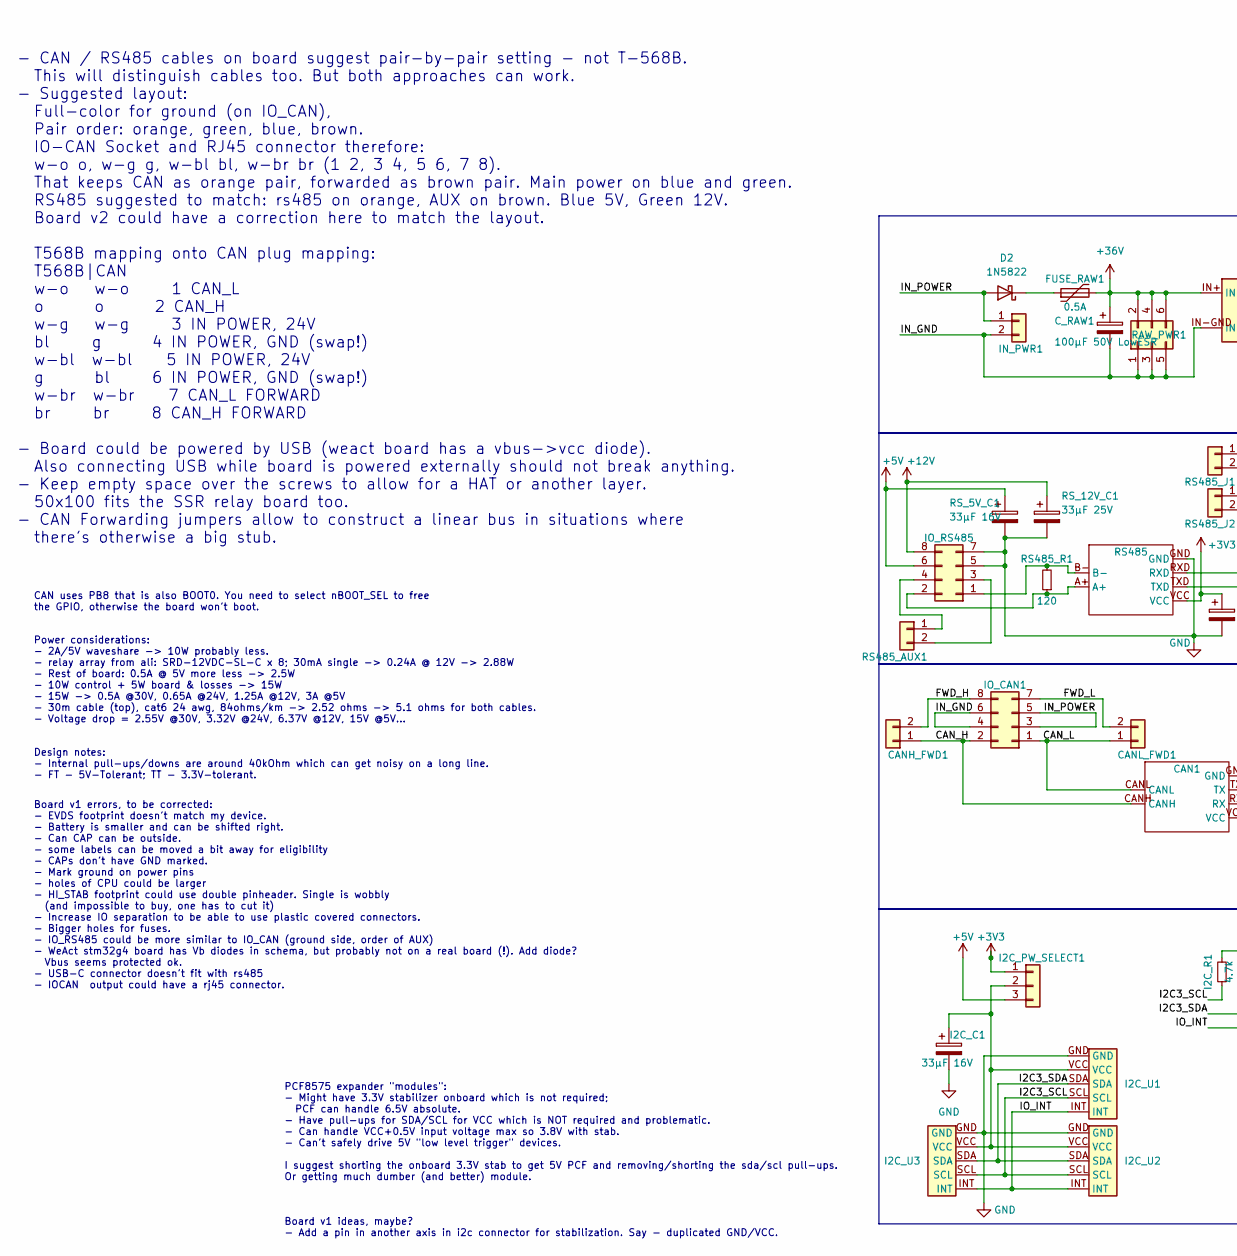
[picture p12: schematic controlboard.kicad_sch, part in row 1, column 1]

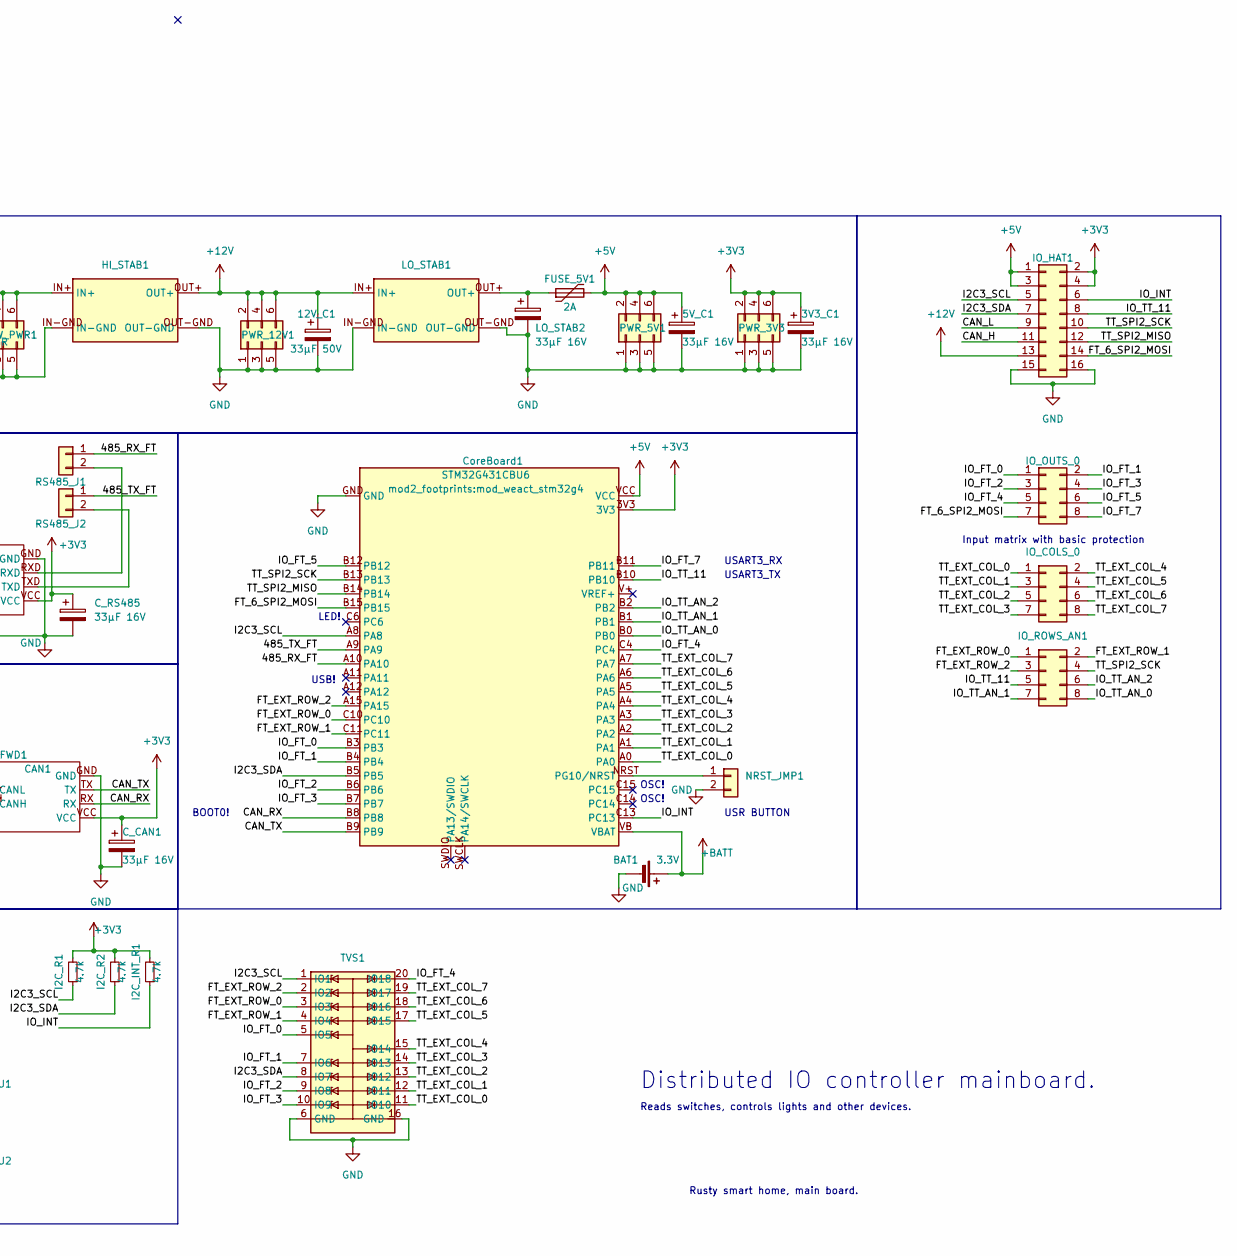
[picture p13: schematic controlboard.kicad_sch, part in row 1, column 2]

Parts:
3V3_C1, 5V_C1: 33µF 16V; C_Radial_D4.0mm_H7.0mm_P1.50mm
12V_C1: 33µF 50V; C_Radial_D5.0mm_H7.0mm_P2.00mm
BAT1: 3.3V; BatteryHolder_ComfortableElectronic_CH273-2450_1x2450
CAN1: mod_tja1050_can
CANH_FWD1: Conn_01x02; PinHeader_1x02_P2.54mm_Vertical
CANL_FWD1: Conn_01x02; PinHeader_1x02_P2.54mm_Vertical
C_CAN1: 33µF 16V; C_Radial_D4.0mm_H7.0mm_P1.50mm
C_RAW1: 100µF 50V LowESR; C_Radial_D10.0mm_H12.5mm_P5.00mm
C_RS485: 33µF 16V; C_Radial_D4.0mm_H7.0mm_P1.50mm
CoreBoard1: STM32G431CBU6; mod_weact_stm32g4
D2: 1N5822; D_DO-201AD_P15.24mm_Horizontal
FUSE_5V1: 2A; Fuse_BelFuse_0ZRE0016FF_L9.9mm_W3.8mm
FUSE_RAW1: 0.5A; Fuse_BelFuse_0ZRE0016FF_L9.9mm_W3.8mm
HI_STAB1: mod_LM2596
I2C_C1: 33µF 16V; C_Radial_D4.0mm_H7.0mm_P1.50mm
I2C_INT_R1, I2C_R1, I2C_R2: 4.7k; R_0805_2012Metric_Pad1.20x1.40mm_HandSolder
I2C_PW_SELECT1: Conn_01x03; PinHeader_1x03_P2.54mm_Vertical
I2C_U1, I2C_U2, I2C_U3: mod_pcf8575_16bit_vertical
IN_PWR1: Conn_01x02; PinHeader_1x02_P2.54mm_Vertical
IO_CAN1: Conn_02x04_Odd_Even; PinHeader_2x04_P2.54mm_Vertical
IO_COLS_0: Conn_02x04_Odd_Even; PinHeader_2x04_P2.54mm_Vertical
IO_HAT1: Conn_02x08_Odd_Even; PinHeader_2x08_P2.54mm_Vertical
IO_OUTS_0: Conn_02x04_Odd_Even; PinHeader_2x04_P2.54mm_Vertical
IO_ROWS_AN1: Conn_02x04_Odd_Even; PinHeader_2x04_P2.54mm_Vertical
IO_RS485: Conn_02x04_Odd_Even; PinHeader_2x04_P2.54mm_Vertical
LO_STAB1: mod_mp1584_stab
LO_STAB2: 33µF 16V; C_Radial_D5.0mm_H7.0mm_P2.00mm
NRST_JMP1: Conn_01x02; PinHeader_1x02_P2.54mm_Vertical
PWR_3V3, PWR_5V1, PWR_12V1: Conn_02x03_Odd_Even; PinHeader_2x03_P2.54mm_Vertical
RAW_PWR1: Conn_02x03_Odd_Even; PinHeader_2x03_P2.54mm_Vertical
RS485: mod_hw-0519-rs-485
RS485_AUX1, RS485_J1, RS485_J2: Conn_01x02; PinHeader_1x02_P2.54mm_Vertical
RS485_R1: 120; R_0805_2012Metric_Pad1.20x1.40mm_HandSolder
RS_5V_C1: 33µF 16V; C_Radial_D4.0mm_H7.0mm_P1.50mm
RS_12V_C1: 33µF 25V; C_Radial_D4.0mm_H7.0mm_P1.50mm
TVS1: SO-20_5.3x12.6mm_P1.27mm

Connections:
+3V3: 3V3_C1.1, CAN1.VCC, C_CAN1.1, C_RS485.1, CoreBoard1.3V3, I2C_INT_R1.2, I2C_PW_SELECT1.1, I2C_R1.2, I2C_R2.2, IO_HAT1.2, IO_HAT1.4, PWR_3V3.2, PWR_3V3.4, PWR_3V3.6, RS485.VCC
+5V: 5V_C1.1, CoreBoard1.VCC, FUSE_5V1.2, I2C_PW_SELECT1.3, IO_HAT1.1, IO_HAT1.3, IO_RS485.6, PWR_5V1.2, PWR_5V1.4, PWR_5V1.6, RS_5V_C1.1
+12V: 12V_C1.1, HI_STAB1.OUT+, IO_HAT1.13, IO_RS485.8, LO_STAB1.IN+, PWR_12V1.2, PWR_12V1.4, PWR_12V1.6, RS_12V_C1.1
+36V: C_RAW1.1, FUSE_RAW1.2, HI_STAB1.IN+, RAW_PWR1.2, RAW_PWR1.4, RAW_PWR1.6
+BATT: BAT1.1 (+), CoreBoard1.VB (VBAT)
/485_RX_FT: CoreBoard1.A10, RS485_J1.1
/485_TX_FT: CoreBoard1.A9, RS485_J2.1
/CAN_H: CAN1.CANH, CANH_FWD1.1, IO_CAN1.2, IO_HAT1.11
/CAN_L: CAN1.CANL, CANL_FWD1.1, IO_CAN1.1, IO_HAT1.9
/CAN_RX: CAN1.RX, CoreBoard1.B8
/CAN_TX: CAN1.TX, CoreBoard1.B9
/FT_6_SPI2_MOSI: CoreBoard1.B15, IO_HAT1.14, IO_OUTS_0.7
/FT_EXT_ROW_0: CoreBoard1.C10, IO_ROWS_AN1.1, TVS1.3 (IO3)
/FT_EXT_ROW_1: CoreBoard1.C11, IO_ROWS_AN1.2, TVS1.4 (IO4)
/FT_EXT_ROW_2: CoreBoard1.A15, IO_ROWS_AN1.3, TVS1.2 (IO2)
/I2C3_SCL: CoreBoard1.A8, I2C_R1.1, I2C_U1.SCL, I2C_U2.SCL, I2C_U3.SCL, IO_HAT1.5, TVS1.1 (IO1)
/I2C3_SDA: CoreBoard1.B5, I2C_R2.1, I2C_U1.SDA, I2C_U2.SDA, I2C_U3.SDA, IO_HAT1.7, TVS1.8 (IO7)
/IN_GND: C_RAW1.2, HI_STAB1.IN-GND, IN_PWR1.2, IO_CAN1.4, IO_CAN1.6, RAW_PWR1.1, RAW_PWR1.3, RAW_PWR1.5
/IN_POWER: D2.2 (A), IN_PWR1.1, IO_CAN1.3, IO_CAN1.5
/IO_FT_0: CoreBoard1.B3, IO_OUTS_0.1, TVS1.5 (IO5)
/IO_FT_1: CoreBoard1.B4, IO_OUTS_0.2, TVS1.7 (IO6)
/IO_FT_2: CoreBoard1.B6, IO_OUTS_0.3, TVS1.9 (IO8)
/IO_FT_3: CoreBoard1.B7, IO_OUTS_0.4, TVS1.10 (IO9)
/IO_FT_4: CoreBoard1.C4, IO_OUTS_0.5, TVS1.20 (IO18)
/IO_FT_5: CoreBoard1.B12, IO_OUTS_0.6
/IO_FT_7: CoreBoard1.B11, IO_OUTS_0.8
/IO_INT: CoreBoard1.C13, I2C_INT_R1.1, I2C_U1.INT, I2C_U2.INT, I2C_U3.INT, IO_HAT1.6
/IO_TT_11: CoreBoard1.B10, IO_HAT1.8, IO_ROWS_AN1.5
/IO_TT_AN_0: CoreBoard1.B0, IO_ROWS_AN1.8
/IO_TT_AN_1: CoreBoard1.B1, IO_ROWS_AN1.7
/IO_TT_AN_2: CoreBoard1.B2, IO_ROWS_AN1.6
/TT_EXT_COL_0: CoreBoard1.A0, IO_COLS_0.1, TVS1.11 (IO10)
/TT_EXT_COL_1: CoreBoard1.A1, IO_COLS_0.3, TVS1.12 (IO11)
/TT_EXT_COL_2: CoreBoard1.A2, IO_COLS_0.5, TVS1.13 (IO12)
/TT_EXT_COL_3: CoreBoard1.A3, IO_COLS_0.7, TVS1.14 (IO13)
/TT_EXT_COL_4: CoreBoard1.A4, IO_COLS_0.2, TVS1.15 (IO14)
/TT_EXT_COL_5: CoreBoard1.A5, IO_COLS_0.4, TVS1.17 (IO15)
/TT_EXT_COL_6: CoreBoard1.A6, IO_COLS_0.6, TVS1.18 (IO16)
/TT_EXT_COL_7: CoreBoard1.A7, IO_COLS_0.8, TVS1.19 (IO17)
/TT_SPI2_MISO: CoreBoard1.B14, IO_HAT1.12
/TT_SPI2_SCK: CoreBoard1.B13, IO_HAT1.10, IO_ROWS_AN1.4
GND: 3V3_C1.2, 5V_C1.2, 12V_C1.2, BAT1.2 (-), CAN1.GND, C_CAN1.2, C_RS485.2, CoreBoard1.GND, HI_STAB1.OUT-GND, I2C_C1.2, I2C_U1.GND, I2C_U2.GND, I2C_U3.GND, IO_HAT1.15, IO_HAT1.16, IO_RS485.5, IO_RS485.7, LO_STAB1.IN-GND, LO_STAB1.OUT-GND, LO_STAB2.2, NRST_JMP1.2, PWR_3V3.1, PWR_3V3.3, PWR_3V3.5, PWR_5V1.1, PWR_5V1.3, PWR_5V1.5, PWR_12V1.1, PWR_12V1.3, PWR_12V1.5, RS485.GND, RS_5V_C1.2, RS_12V_C1.2, TVS1.6 (GND), TVS1.16 (GND); also elsewhere on the board
unnamed: CANH_FWD1.2, IO_CAN1.8
unnamed: CANL_FWD1.2, IO_CAN1.7
unnamed: CoreBoard1.NRST (PG10/NRST), NRST_JMP1.1
unnamed: D2.1 (K), FUSE_RAW1.1
unnamed: FUSE_5V1.1, LO_STAB1.OUT+, LO_STAB2.1
unnamed: I2C_C1.1, I2C_PW_SELECT1.2, I2C_U1.VCC, I2C_U2.VCC, I2C_U3.VCC
unnamed: IO_RS485.1, RS485.B-, RS485_R1.2
unnamed: IO_RS485.2, RS485.A+, RS485_R1.1
unnamed: IO_RS485.3, RS485_AUX1.2
unnamed: IO_RS485.4, RS485_AUX1.1
unnamed: RS485.RXD, RS485_J1.2
unnamed: RS485.TXD, RS485_J2.2

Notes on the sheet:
USR BUTTON
Rusty smart home, main board.
PCF8575 expander "modules": - Might have 3.3V stabilizer onboard which is not required; PCF can handle 6.5V absolute. - Have pull-ups for SDA/SCL for VCC which is NOT required and problematic. - Can handle VCC+0.5V input voltage max so 3.8V with stab. - Can't safely drive 5V "low level trigger" dev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
BOOT0!
LED!
- CAN / RS485 cables on board suggest pair-by-pair setting - not T-568B. This will distinguish cables too. But both approaches can work. - Suggested layout: Full-color for ground (on IO_CAN), Pair order: orange, green, blue, brown. IO-CAN Socket and RJ45 connector therefore: w-o o, w-g g, w-bl bl, 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
Reads switches, controls lights and other devices.
USB!
Power considerations: - 2A/5V waveshare -> 10W probably less. - relay array from ali: SRD-12VDC-SL-C x 8; 30mA single -> 0.24A @ 12V -> 2.88W - Rest of board: 0.5A @ 5V more less -> 2.5W - 10W control + 5W board & losses -> 15W - 15W -> 0.5A @30V, 0.65A @24V, 1.25A @12V, 3A @5V - 30m cable (top), c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
Board v1 ideas, maybe? - Add a pin in another axis in i2c connector for stabilization. Say - duplicated GND/VCC.
CAN uses PB8 that is also BOOT0. You need to select nBOOT_SEL to free the GPIO, otherwise the board won't boot.
Board v1 errors, to be corrected: - EVDS footprint doesn't match my device. - Battery is smaller and can be shifted right. - Can CAP can be outside. - some labels can be moved a bit away for eligibility - CAPs don't have GND marked. - Mark ground on power pins - holes of CPU could be larger - HI_ST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
OSC!
Distributed IO controller mainboard.
Design notes: - Internal pull-ups/downs are around 40kOhm which can get noisy on a long line. - FT - 5V-Tolerant; TT - 3.3V-tolerant.
Input matrix with basic protection
USART3_RX
USART3_TX

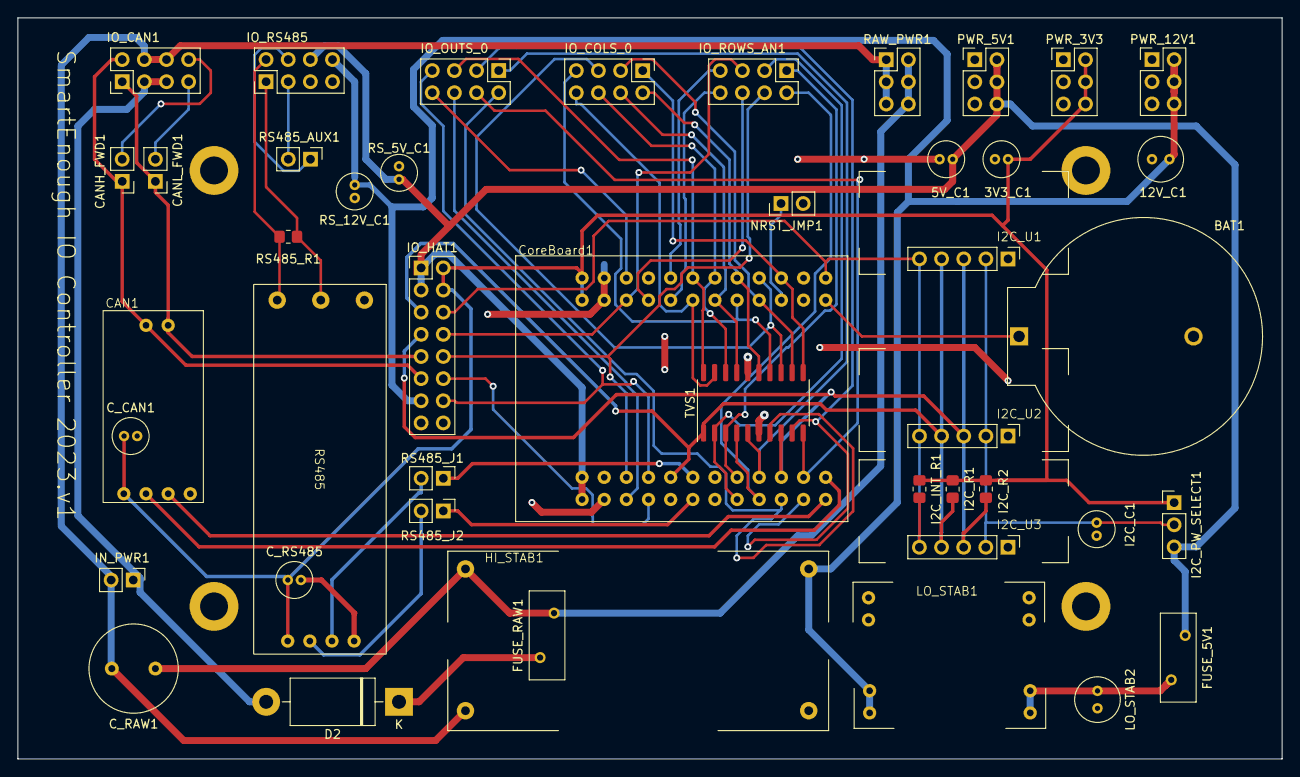
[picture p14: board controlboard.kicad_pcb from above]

Board: 2 copper layers, 145.0 x 85.0 mm, 49 parts (0 on the bottom side), 54 nets.

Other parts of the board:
MHOLE_BL: MountingHole_3.2mm_M3_DIN965_Pad
MHOLE_RB: MountingHole_3.2mm_M3_DIN965_Pad
MHOLE_RT: MountingHole_3.2mm_M3_DIN965_Pad
MHOLE_TL: MountingHole_3.2mm_M3_DIN965_Pad

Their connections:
GND: MHOLE_BL.1, MHOLE_RB.1, MHOLE_RT.1, MHOLE_TL.1; also elsewhere on the board

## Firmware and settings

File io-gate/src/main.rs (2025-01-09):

use clap::Parser;
use io_gate::comm;
use io_gate::config::Config;
use io_gate::homeassistant::{self, discovery, HomeAssistant};
use io_gate::message::{args::OutputState, Message};
use tracing::info;
use tracing_subscriber::{EnvFilter, fmt};
use tracing_subscriber::filter::LevelFilter;


#[derive(Parser, Debug)]
struct Args {
    #[arg(long, default_value = "config.yaml")]
    config_path: String,

    // USB Connection
    #[arg(long, default_value = "/dev/ttyACM0")]
    port_name: String,
    #[arg(long, default_value_t = 115200)]
    baud_rate: u32,

    // MQTT connection
    #[arg(long)]
    mqtt_host: String,
    #[arg(long, default_value_t = 1883)]
    mqtt_port: u16,
    #[arg(long, default_value = "")]
    mqtt_username: String,
    #[arg(long, default_value = "")]
    mqtt_password: String,

    // Other
    #[arg(long, default_value = "io-gate")]
    device_name: String,
}

fn init_log() {
    let timer = fmt::time::ChronoLocal::new("%H:%M:%S%.3f".to_string());

    // Configure a custom event formatter
    let format = fmt::format()
        .with_level(true)
        .with_target(false)
        .with_thread_ids(false)
        .with_thread_names(false)
        .with_file(false)
        .with_source_location(true)
        .with_timer(timer)
        .compact();

    let filter = EnvFilter::builder()
        .with_default_directive(LevelFilter::DEBUG.into())
        .from_env().expect("RUST_LOG configuration is valid")
        .add_directive("rumqttc=info".parse().unwrap());

    fmt()
        .event_format(format)
        .with_env_filter(filter)
        .init();
}

/// Perform initial configuration and device discovery.
async fn init_config(config: &Config, ha: &HomeAssistant) -> anyhow::Result<()> {
    for (device_name, cfg) in &config.devices {
        let message = discovery::new_device(device_name, cfg);

        // Subscribe to HomeAssistant state changes.
        for component in message.components.values() {
            ha.send(homeassistant::Outgoing::Subscribe(component.command_topic.clone())).await?;
        }

        // Send discovery message to register/update device in HA.
        ha.send(homeassistant::Outgoing::DiscoveryDevice(message))
            .await?;
    }

    Ok(())
}

#[tokio::main]
async fn main() -> anyhow::Result<()> {
    init_log();
    let args = Args::parse();

    let config = Config::from_file(&args.config_path)?;
    info!("Starting IO Gate. Args: {:?} Config: {:?}", args, config);

    let mut ha_init = homeassistant::Initiator::new(
        "io-gate-mqtt",
        &args.mqtt_host,
        args.mqtt_port,
        &args.mqtt_username,
        &args.mqtt_password,
    )
    .await;
    ha_init.set_topics("iogatetest", "iogatepub").await;
    let ha = ha_init.start().await;

    ha.send(homeassistant::Outgoing::Initial)
        .await
        .expect("Should send");

    init_config(&config, &ha).await?;

    let mut comm = comm::run(args.port_name, args.baud_rate).await?;

    info!("io-gate initialized.");

    // USB -> MQTT
    tokio::spawn(async move {
        // TEMP: Receiver
        loop {
            let msg = if let Some(msg) = comm.rx.recv().await {
                msg
            } else {
                // The other end died.
                break;
            };
            let msg = Message::from_raw(msg);
            info!("CAN->RX: Message {:?}", msg);
        }
    });

    // MQTT -> USB
    tokio::spawn(async move {
        loop {
            let msg = if let Some(msg) = ha.recv().await {
                msg
            } else {
                // The other side died.
                break;
            };

            match msg {
                homeassistant::Incoming::RawTest(_vec) => {
                    info!("Raw test message received");
                }
                homeassistant::Incoming::SetOutput { device, output, on } => {
                    let msg = Message::SetOutput {
                        output,
                        state: OutputState::from_bool(on),
                    };
                    let addr = device;
                    let raw = msg.to_raw(addr);
                    info!("Sending output change request over USB {:?}", raw);
                    if comm.tx.send(raw).await.is_err() {
                        break;
                    }
                },
            }
        }
    });

    // TODO: Periodic time updates

    // Wait for tasks.
    let (reader_ret, writer_ret) = tokio::try_join!(comm.reader, comm.writer)?;
    reader_ret?;
    writer_ret?;
    Ok(())
}

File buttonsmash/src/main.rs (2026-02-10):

/*
 * Use cases:
 * - Outputs can be active-high or active-low.
 * - Inputs can be active-high or active-low.
 * - Inputs and outputs can use native µC pins or expander IOs.
 * - Output can have a maximum activation time and be disabled even if button is still held (shutters).
 *
 * - A push-button toggles state of a single local output.
 * - Multiple buttons controls a IO that might be local or remote.
 * - Button can control multiple IOs. Up to.. X? "Scene".
 * - Button can control a scene that `has a state`?
 * - Stair or long corridor control. Button TOGGLES the output, no matter what is the
 *   state. One controller has the output and 1 or more inputs correlated.
 * - Button has different action when short-clicked or when held longer.
 * - Holding a button can cause a single-shot action (toggle light/scene) or change a layer.
 * - Layer changes actions locally assigned to buttons. Some buttons can be
 *   "transparent" on a layer and keep the same action.
 * - MAYBE: layers could be triggered remotely.
 * - Input/output configuration can be static/compiled. It's hardware dependent.
 * - Input->output mapping and scenes should be dynamically programmable.
 * - Pressing a button activates Output for a set amount of time.
 *
 * Analysis:
 * Living room + kitchen + dining room setup + terrace
 * Inputs: (2+3+2) * 2 inputs = 14 inputs.
 * Lights:
 * - Kitchen lights: 2 + Leds?
 * - Dining room: 1+1+1
 * - Living room: 1+1+1 (+1?)
 * - Terrace: 2
 * - Corridor light (remote, not physical): 1
 * Drapes: 5 with 2 directions -> 10. Not physical, remote.
 * Total: 11 outputs... or 21.
 *
 * Possible "scenes" ("partial" scenes?):
 * - Everything on/off (including wall-lights/ambients?)
 * - Kitchen on/off (ceiling + island)
 * - Ambient lighting (wall light ON, rest OFF).
 * - Ceiling lights: kitchen
 * - Ceiling lights: living room
 * - Ceiling lights: dining room
 * - Ceiling lights all on (or off) - as a group
 * - Kitchen island lights
 * - Living room dining table
 * - Kitchen island + dining table
 * - Ambient dining (table + island)
 *
 * Disabling a scene should...:
 * - turn off all things that are turned on by a scene and set off all the
 *   things that are turned off by it? Or rather turn off what is turned on and
 *   keep the rest as is?
 *
 * - toggling a scene needs information about its state or "if at least one of
 *   its lights is enabled assume the scene is on".
 */

/*
 * Layers in a distributed system.
 *
 * Those would work a bit differently than in QMK. Layer being active would need
 * a regular "yeah it's still up" and have a timeout. Deactivate not strictly
 * needed. Still. Do we need this?
 *
 * IOs can be remote, but layers should work within the single controller. Also,
 * someone hitting a button upstrairs, shouldn't not alter the behaviour
 * downstairs.
 *
 */

#[tokio::main]
async fn main() {
    println!("Main starts!");
}

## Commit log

2024-06-09 Buttonsmash: testing io concepts on amd64.
2024-06-13 Microvm executes simple static opcodes with bindings lookup.
    [main.rs]
2025-01-02 Bidirectional communication seems to work.
    Path:
    PC gate tx --USB--> board --CAN--> loopback --> board --USB--> PC
    - Message code partially duplicated.
    - Migration to tracing in progress.
    - MQTT + HA discovery is next.
2025-01-06 Improve device naming (use aliases)
2025-01-09 Discovery + setting state changes works.
    Updated tracing to filter other crates.
2026-02-10 Green finger, some iteration. Mostly own code here.
2026-02-10 Schematic and board for the smarthome IO controller.
    Version 1. Probably has some problems.
    [controlboard.kicad_pcb, controlboard.kicad_sch]
2026-02-10 Recover from the backup notes on the schematic (errata, etc.)
    [controlboard.kicad_pcb, controlboard.kicad_sch]
2026-02-10 Some old changes to controlboard.
    There should be no true changes though. It's still v1 (one I've deployed). Board
    has too little holes for fuse, otherwise is fine.
    [controlboard.kicad_pcb, controlboard.kicad_sch]
2026-02-10 PowerHub board - power and CAN distribution.
    [power-hub.kicad_pcb, power-hub.kicad_sch]
2026-02-10 ESPHome uniboard.
    [uniboard.kicad_pcb, uniboard.kicad_sch]
2026-02-10 Kicad library, probably necessary for io-ctrl board.
2026-02-10 Universal DIN rail clip - 3D CAD for FreeCAD.
    [universal-din-clip-v3-lower.FCStd]
2026-02-10 8-channel SSR case to protect edges and connect to din rail.
    [SSR_din_case.FCStd]
2026-02-10 Project boxes using YAPPgenerator.
    [SSR_din_case.FCStd, YAPPgenerator_v3.scad, own-smarthome-box.scad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]

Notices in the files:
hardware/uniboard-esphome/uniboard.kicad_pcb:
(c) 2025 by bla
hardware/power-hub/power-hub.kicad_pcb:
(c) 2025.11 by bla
